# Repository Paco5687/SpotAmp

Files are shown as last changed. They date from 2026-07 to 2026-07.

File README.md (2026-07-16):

# SpotAmp 🎛️

**A standalone desktop Spotify player with real motorized faders, physical
buttons, and a WinAmp-inspired soul.** Raspberry Pi + RP2040, open hardware and
software (MIT). It sits on your desk on a pop-out stand, plays Spotify with **no
phone and no cloud remote** — and when you load an EQ preset, the faders
physically glide into place.



> *It really whips the llama's ass.* (Inspired by [Eslam Mohamed's WinAmp
> hardware concept](https://www.yankodesign.com/2024/04/27/modular-media-player-concept-brings-iconic-winamp-design-to-the-physical-world/) — but real, and it plays.)

## The screen (running today on the device)

The center of the unit is a square 720×720 touchscreen (HyperPixel 4.0) running
a compact multi-view UI — switched by dedicated physical buttons:

| Now Playing | Playlists | Up Next |
|---|---|---|
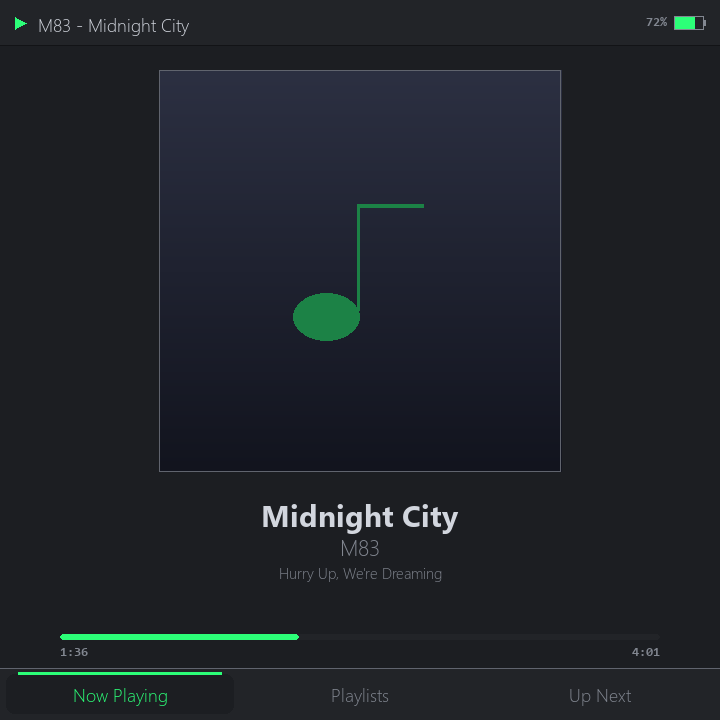
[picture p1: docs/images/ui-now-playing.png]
Now Playing
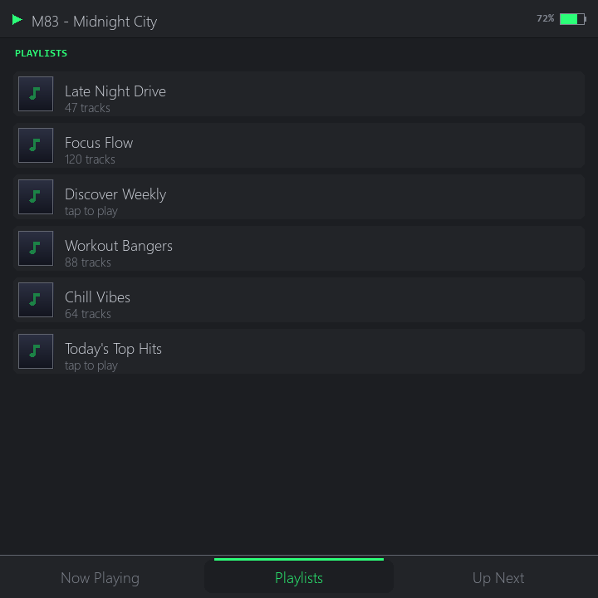
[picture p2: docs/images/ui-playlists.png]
Playlists
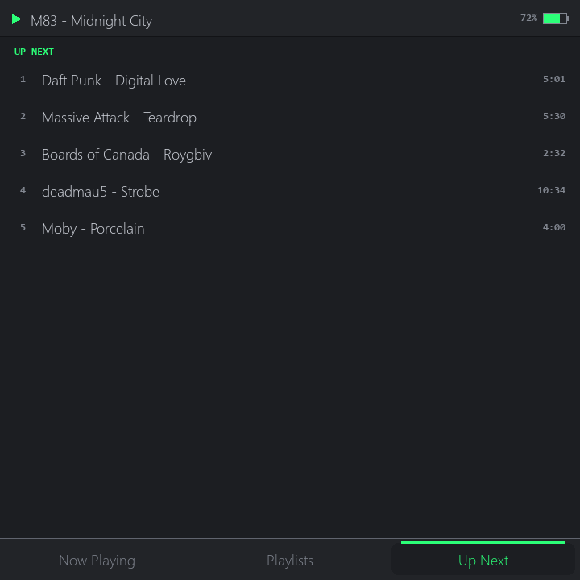
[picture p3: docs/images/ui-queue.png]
Up Next
|  |  |  |

This already runs **standalone on the Pi**: boots straight into the UI (kiosk),
streams via go-librespot, browses your real library, plays through its own
speakers-to-be. Transport, EQ, volume, and seek live in *hardware* — including a
**seek fader that physically tracks the song**.

## The hardware design

| System wiring | RP2040 pinout |
|---|---|
| System wiring | Pico pinout |

**Front panel** — dimensioned, parametric, CAD-ready
([DXF for SketchUp / SVG for Blender](hardware/cad/)):

Front panel cut drawing

Envelope **175 × 280 × 32 mm** (6.9″ × 11″), FDM prototype → CNC **anodized
aluminum** final, with aluminum knobs and a fold-out kickstand.

## How it works

```
        ┌───────────────────────────┐        USB serial        ┌──────────────────────┐
        │     Raspberry Pi 4 B       │◀───────(ASCII)──────────▶│  RP2040 (Pico)       │
        │                            │                          │                      │
        │  go-librespot ─▶ ALSA EQ ─▶│─▶ USB DAC ─▶ amp/spkrs   │  buttons · encoders  │
        │        │            ▲      │                          │  amber OLED readout  │
        │  Spotify Web API    │      │   FADER <id> <pos> ──────▶  10 motorized faders │
        │        │            │      │                          │   (PID position loop)│
        │  multi-view UI ─────┘      │◀──── EV BTN/FADER/BAT ───│  battery · touch     │
        └───────────────────────────┘                          └──────────────────────┘
             720×720 touchscreen                                 I2C: PCA9685×2 · MPR121
                                                                      MCP23017 · TPA2016
```

Two brains: the Pi runs Spotify + the screen; the RP2040 owns real-time I/O and
the fader PID loops. Full detail: [docs/architecture.md](docs/architecture.md) ·
[serial protocol](docs/serial-protocol.md) · [wiring + pin maps](hardware/wiring.md).

## Status

**Working now** — standalone playback on the device (no phone), kiosk boot,
touch UI (now playing / playlists / queue), real album art, Spotify Connect
control path, complete RP2040 firmware (compiled, awaiting parts), dimensioned
panel drawing, full parts list.

**Next** — order parts → single-fader PID bring-up → OLED + buttons → motorized
EQ → speakers/amp → battery → enclosure. Live plan on the
**[project board](https://github.com/users/Paco5687/projects/4)**.

## Build one

| | |
|---|---|
| 🛒 [Parts list](hardware/PARTS.md) | real SKUs, ~$450–515 + Pi/screen |
| 📄 [BOM + rationale](hardware/BOM.md) | why every part is there |
| 🔌 [Wiring & schematics](hardware/wiring.md) | address maps, pin budget, diagrams |
| 📐 [Panel CAD](hardware/cad/) | parametric DXF/SVG generator |
| 🧲 [Enclosure notes](hardware/enclosure.md) | machining rules, kickstand, findings |
| 🥧 [Pi bring-up](docs/pi-bringup.md) | reproducible standalone-player setup |
| 🎹 [Firmware](firmware/) | RP2040, PlatformIO, bench bring-up guide |

Try the UI on any machine (no hardware, no account):

```bash
cd pi && pip install -r requirements.txt && python -m spotamp
```

## The honest hard parts

- **Spotify Premium required** — playback uses [go-librespot](https://github.com/devgianlu/go-librespot)
  (unofficial). Browsing uses the Web API in Dev Mode (see
  [docs/spotify-setup.md](docs/spotify-setup.md) for the one-time standalone auth).
- **Motorized faders are the cost/complexity center** (~$200+ of the build) —
  and the reason this thing will be cool.
- The HyperPixel takes **all 40 GPIO**, so everything else rides USB + an I2C
  expander architecture — see [hardware/wiring.md](hardware/wiring.md).

## Naming & trademarks

SpotAmp is an independent, unofficial hobby project. It is **not affiliated with,
endorsed by, or sponsored by Spotify** (you bring your own Premium account and
developer app), and it is not associated with WinAmp/Llama Group — the UI is an
original homage to the classic WinAmp aesthetic, with no assets from it.

*(Formerly "WinAmpPlayer" — old links redirect.)*

## License

[MIT](LICENSE) — build one, remix it, tell us how it goes.

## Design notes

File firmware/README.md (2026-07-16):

# Firmware (RP2040 / Raspberry Pi Pico)

Owns all physical I/O and the real-time motor loops for the motorized faders.
Talks to the Pi over USB serial using the [serial protocol](../docs/serial-protocol.md).

## Build

Uses [PlatformIO](https://platformio.org/) with the Arduino core for RP2040
(`earlephilhower/arduino-pico`):

```bash
cd firmware
pio run                 # build
pio run -t upload       # flash (hold BOOTSEL on first flash, or use the reset)
pio device monitor      # watch the serial link
```

## What it does

- Reads buttons (via MCP23017), encoders, the balance pot, and all fader wiper
  positions (through a CD74HC4067 analog mux, since the Pico has only 3 ADC
  channels).
- Runs a per-fader **PID loop** at ~1 kHz driving each motorized fader toward the
  target the Pi last sent (`FADER <id> <pos>`), and yields the motor while the
  user is touching that fader (MPR121 touch electrodes).
- Drives the **amber OLED readout** (SSD1322 over SPI) from `DISP` commands the
  Pi streams (title / time / stream info).
- Emits `EV …` events upstream (button presses, user fader moves, touch, encoders).

> **I/O architecture:** motor PWM goes through **2× PCA9685** and buttons/touch
> through **MCP23017/MPR121**, all on one I2C bus — direct-wiring doesn't fit the
> Pico's 26 GPIO. Full pin budget in [../hardware/wiring.md](../hardware/wiring.md).
> The `main.cpp` skeleton still drives one fader on direct pins for bring-up;
> switch to the PCA9685 when scaling past one.

The firmware is **fully built out** (desk-written 2026-07-16, compiles clean,
untested on hardware): every I2C device driver, the OLED readout with the `DISP`
marquee, buttons/encoders/touch/battery events, and the per-fader PID against
the PCA9685. `src/config.h` holds all pins, addresses, and tuning constants —
including **feature flags** (`HAS_PCA9685`, `HAS_OLED`, …) so bench bring-up can
enable one subsystem at a time. A missing I2C board logs `... MISSING` and
degrades instead of hanging.

## Bring-up order (with the full firmware)

1. Flash with **all `HAS_*` flags off except none needed** — `PING`→`PONG` over
   USB proves the link (`LOG spotamp-fw ready`).
2. Enable `HAS_MCP23017` → press buttons, watch `EV BTN`. Encoders are always
   on (direct GPIO) — turn them, watch `EV ENC`.
3. Wire fader #1 (wiper → mux ch0, motor → PCA A ch0/1, touch → MPR121 e0);
   enable `HAS_PCA9685` + `HAS_MPR121`. Send `FADER 0 512` — tune `PID_KP/KD`
   and `PWM_MIN_MOVE` (stiction floor) in `config.h` until it glides.
4. Enable `HAS_OLED` — the Pi's `DISP` stream should show time + title.
5. Enable `HAS_TPA2016` + `HAS_MAX17040` — battery `EV BAT` every 5 s, jack
   insert mutes the amp.
6. Scale to all 10 faders.

⚠️ Safety built in: PCA9685 **/OE is held high (motors disabled) until the
firmware has zeroed all channels** — no fader slam on boot.

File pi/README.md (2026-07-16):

# Pi app — `spotamp`

The Python/Pygame application: the WinAmp-style UI, Spotify control, and the
bridge to the microcontroller. Runs **fully mocked on a laptop** so you can build
the UI with no hardware and no Spotify account.

## Run (mock mode — default)

```bash
cd pi
pip install -r requirements.txt   # pygame is all you need for mock mode
python -m spotamp
```

Requires **Python 3.11+** (uses the stdlib `tomllib`).

A square (720×720) **multi-view** window opens — the device screen: **Now Playing**,
**Playlists**, **Up Next**. On the real device these views are switched by dedicated
physical buttons; transport/EQ/faders are hardware, not on screen.

**Controls in the window (dev):**

| Input | Action |
|---|---|
| Tabs / `1` `2` `3` / `Tab` | switch view (Now Playing / Playlists / Up Next) |
| Tap a playlist row | open + play that playlist |
| `space` | play/pause |
| `←` / `→` | prev / next |
| `↑` / `↓` | volume |
| `s` | stop · `q` / `Esc` quit |

## Connect Spotify (Web API — playlists & album art)

No website or hosting needed — it uses a **loopback redirect + PKCE**.

1. Create an app at https://developer.spotify.com/dashboard.
2. Add this **exact** redirect URI (Spotify banned `localhost`; loopback HTTP is fine):
   ```
   http://127.0.0.1:8888/callback
   ```
3. Put the app's **Client ID** in `config.toml` as `spotify_client_id` (no secret needed).
4. Authorize once:
   ```bash
   python -m spotamp.authorize
   ```
   A browser opens, you approve, and a refresh token is cached to
   `pi/spotify_token.json` (gitignored). The device refreshes tokens forever after that.

`go-librespot` (the audio playback) authenticates **separately and standalone** —
using its own one-time **interactive OAuth** login (no phone required; a phone via
Spotify Connect is only an optional alternative). It needs Premium. See
[../docs/spotify-setup.md](../docs/spotify-setup.md) for both one-time logins.

## Run against real hardware

Copy `config.example.toml` → `config.toml` and set:

```toml
backend  = "librespot"      # needs a running go-librespot + Spotify Premium
controls = "serial"         # needs the RP2040 flashed and connected
serial_port = "/dev/ttyACM0"
fullscreen = true           # on the device LCD
```

`requests` and `pyserial` (in `requirements.txt`) are only needed for real
hardware; they're imported lazily so mock mode doesn't require them.

## Layout

```
spotamp/
├── __main__.py      # python -m spotamp (also: `authorize` subcommand)
├── app.py           # main loop, action routing, MOTOR SYNC, queue/battery polls
├── config.py        # config.toml loader (zero-config defaults)
├── models.py        # PlayerState / Track — the source of truth
├── spotify.py       # MockPlayer / WebApiPlayer / LibrespotPlayer (PlayerBackend)
├── spotify_web.py   # Web API client: playlists, queue, playback control
├── spotify_auth.py  # loopback PKCE OAuth + token cache
├── library.py       # async playlist browsing (BrowseState)
├── images.py        # async album-art download + cache
├── power.py         # battery sources (mock / Geekworm X728)
├── controls.py      # serial protocol + MockControls / SerialControls
└── ui/
    ├── skin.py      # palette + Rect drawing helper
    └── screen.py    # the multi-view screen UI (Now Playing / Playlists / Up Next)
```

Tests live in [`tests/`](tests/) — run `python -m pytest tests` from `pi/`.
See [../docs/architecture.md](../docs/architecture.md) for how it all fits.

## Playback backends

Set `backend` in `config.toml`:

| `backend` | What plays the audio | Use it for |
|---|---|---|
| `mock` (default) | nothing — simulated playback of a demo/owned playlist | UI dev on a laptop |
| `librespot` | **go-librespot on this machine** (the device path) | the real device |
| `webapi` | any active Spotify Connect device via the Web API | laptop dev with real audio |

Tapping a playlist plays it **by context URI**, which works for owned *and*
followed/editorial playlists (Dev Mode only restricts *reading* their track
lists, not playing them). The **Up Next** view shows the live playback queue
(`GET /me/player/queue`), so you still get a tracklist for anything playing.

## Notes / TODO

- **Album art** is real (fetched + cached async in `images.py`); a drawn
  placeholder shows until each image lands.
- **Spectrum analyzer** returns in Phase 4 with the real FFT audio tap.
- **EQ** currently just stores band gains; the ALSA software-EQ pipeline that
  applies them is Phase 4 (see the project board).

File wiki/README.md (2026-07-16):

# Wiki source

These Markdown files are the **source for the GitHub Wiki**. GitHub stores a
wiki in a separate git repo (`SpotAmp.wiki.git`), so to publish:

1. Create the wiki by adding one page in the repo's **Wiki** tab (this
   initializes `….wiki.git`).
2. `git clone git@github.com:Paco5687/SpotAmp.wiki.git`
3. Copy these files in, `git add -A && git commit && git push`.

Page names map to titles (`Bill-of-Materials.md` → "Bill of Materials").
`Home.md` is the landing page; `_Sidebar.md` is the nav. **Placeholders for now** —
most pages link to the authoritative docs under [`/docs`](../docs) and
[`/hardware`](../hardware) so there's a single source of truth.

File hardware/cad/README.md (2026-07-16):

# CAD — front panel

**`front-panel.dxf`** (SketchUp Pro / any CAD) and **`front-panel.svg`**
(Blender-native curve import) are both generated from
[`generate_panel.py`](generate_panel.py) — one parametric source of truth where
every dimension is a named constant traced to a datasheet. **Don't hand-edit the
DXF/SVG; edit the parameters and regenerate** (`python generate_panel.py`).

Current envelope: **175 × 280 × 32 mm** (see the height/width findings in
[../enclosure.md](../enclosure.md) — the fader mounting span drives everything).

## Layers

| Layer | Meaning | Action in CAD |
|---|---|---|
| `OUTLINE` | panel perimeter (R4 corners) | cut |
| `CUTOUTS` | windows + fader/pot slots + button holes | cut through |
| `HOLES` | mounting screw holes (true diameters: M3 clearance 3.4, pot mounts 2.4) | drill |
| `GRILLE` | speaker grille pattern (ø2, hex pitch 4.5) | drill |
| `ENGRAVE` | labels | engrave/laser — **do not cut** |
| `REF` | component bodies **behind** the panel (faders, OLED, HyperPixel) | placement aid — **delete before cutting** |
| `DIM` | notes | delete after import |

## Import

**SketchUp Pro**: File → Import → DXF, units **millimeters**. Each layer arrives
as a tag. To make the 3D panel: select the outline + cut layers → Push/Pull to
panel thickness (2–3 mm), using `REF` to position the component models. The ALPS
fader **STEP model** is downloadable from the ALPS product page (link in
[../datasheets/README.md](../datasheets/README.md)).

**Blender**: File → Import → SVG (native). Curves arrive true-to-mm (1 unit =
1 mm at default SVG import scale — verify with the 175 mm outline). Extrude the
curves for the panel solid.

## Before cutting anything

- Cross-check every **VERIFY**-marked constant in `generate_panel.py` against the
  physical part (fader M3 span & slot, HyperPixel bezel, OLED window, slide-pot
  mounts) — datasheet revisions and clone parts vary.
- The checker enforces 2D clearances only. Two known **3D stacking questions**
  for CAD: (1) transport-button PCB vs the volume fader body (~0.75 mm apart
  behind the panel), (2) grille back-volume vs the seek fader motor. Both have
  room to shift a few mm if needed — change the constant, regenerate.
- Grille zones are modest (24×16 mm each); the side walls can carry additional
  grille if the speakers want more open area — that's a body decision, not a
  panel one.

## Sanity checks built into the generator

Bounds (everything inside the walls) + all-pairs clearance between every cut
feature (circle/rect/rect-circle, ≥1.5 mm). The generator **refuses to emit** a
drawing that fails — extend the checks rather than bypassing them.

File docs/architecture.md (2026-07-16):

# Architecture

## Why two brains

The Pi runs Linux, which is non-deterministic under scheduling load — fine for
UI and networking, bad for a tight motor-control loop that has to run at a
steady ~1 kHz to keep motorized faders from oscillating. So:

- **Raspberry Pi** — Spotify client, audio pipeline, the LCD UI, high-level
  logic. Sends *targets* ("move volume fader to 72%").
- **RP2040 microcontroller** — soft-real-time I/O. Owns the PID loops that drive
  each motorized fader to its target, debounces buttons, reads pots/encoders,
  and streams events up to the Pi.

They talk over a simple newline-delimited ASCII protocol on USB serial. See
[serial-protocol.md](serial-protocol.md).

## Alternative platforms (future / v2)

The **[Arduino Uno Q](https://docs.arduino.cc/hardware/uno-q/)** is architecturally
this exact design on a single board: a Qualcomm Dragonwing QRB2210 (quad
Cortex-A53, runs Debian Linux) **plus** an STM32U585 (Cortex-M33) real-time MCU,
with an internal bridge — i.e. our "Pi brain + RP2040 brain" fused, plus eMMC.

We're **staying on Pi 4 B + RP2040 for v1** because: the Uno Q's MIPI-DSI display
and analog audio come out only via a separate carrier board; it's brand-new
(Oct 2025) with an unproven ecosystem/supply — risky for a build others must
reproduce; and we already have a working Pi stack. It's a strong **v2 candidate**
if its ecosystem matures — it could collapse both boards into one.

## Audio path

```
Spotify ──▶ go-librespot ──▶ ALSA (software graphic EQ) ──▶ USB DAC ──▶ switched 3.5mm jack
                                    ▲                  │                     │ (no plug)
                          EQ gains from faders         │              TPA2016 amp ──▶ internal
                                                       │             (I2C, RP2040 bus)  speakers
                                          audio tap ──▶ FFT ──▶ spectrum bars (UI)
```

> The DAC is **USB** (not a GPIO I2S HAT) because the HyperPixel display's DPI
> interface consumes all 40 GPIO pins, including I2S. The Pi's 3.5 mm jack works
> for bring-up. **Standalone playback** comes from internal enclosed speakers via
> a TPA2016 Class-D amp; inserting headphones mutes the amp (jack detect →
> firmware). External outputs are software: **Spotify Connect transfer** (Sonos &
> co. via the Web API — no audio plumbing) and **Bluetooth A2DP** from the Pi 4's
> onboard radio.

- **go-librespot** is a full Spotify client that streams and decodes audio
  directly (requires Premium). It authenticates **standalone via interactive
  OAuth** — a one-time browser login, then it reconnects on cached credentials
  forever, no phone. It exposes an HTTP + WebSocket API for transport and
  now-playing metadata. (Zeroconf/"pick it from a phone" is an optional mode we
  don't rely on.)
- The **graphic EQ is ours** — Spotify exposes no EQ over the API, so we insert a
  software EQ into the ALSA chain (e.g. an `ladspa`/`caps` multi-band plugin, or
  a custom filter). The motorized EQ faders set its band gains.
- A **loopback/monitor tap** feeds a small FFT so the spectrum analyzer reflects
  the actual audio, not a simulation. (In mock mode it's simulated.)

## The Pi app (`pi/spotamp/`)

| Module | Responsibility |
|---|---|
| `models.py` | `PlayerState`, `Track` — the single source of truth the UI renders |
| `spotify.py` | `MockPlayer` (simulation), `WebApiPlayer` (drive any Connect device), `LibrespotPlayer` (the on-device player) behind one `PlayerBackend` interface |
| `spotify_web.py` / `spotify_auth.py` | Web API client (playlists, queue, control) + loopback-PKCE auth |
| `library.py` / `images.py` / `power.py` | Async playlist browsing, album-art cache, battery sources |
| `controls.py` | Serial protocol + `MockControls` / `SerialControls` |
| `ui/skin.py` | Palette + shared drawing helpers |
| `ui/screen.py` | Compact **multi-view** screen UI (Now Playing / Playlists / Queue) for the square LCD; turns touch/buttons into actions |
| `app.py` | Main loop, action routing, and **motor sync** |

### Motor sync — the signature trick

Every frame, `app._sync_motors()` computes where each motorized fader *should*
be from `PlayerState` (volume, seek progress, EQ band gains) and sends a
`FADER <id> <pos>` target — **unless the user is currently touching that fader**
(tracked via `EV TOUCH` events). So:

- Change the song → the **seek fader glides** to the new position and tracks it.
- Load an EQ preset → the **EQ faders physically animate** into the curve.
- Grab a fader → the motor yields; when you let go, it holds your value.

### Backend abstraction

`PlayerBackend` is a `Protocol`. `MockPlayer` advances a demo playlist with no
network so the entire UI is buildable on a laptop. `LibrespotPlayer` maps the
same methods onto go-librespot's local HTTP API (the on-device path);
`WebApiPlayer` drives any active Spotify Connect device through the Web API
(useful for laptop dev with real audio). Swap via `config.toml`.

## Central screen & UI direction

The device is **physical-first**: transport, EQ, and faders are hardware; the
screen is a small **square** LCD (**HyperPixel 4.0 Square, 720×720**) showing the
compact **multi-view** UI in `ui/screen.py` — one view at a time, switched by
**dedicated physical buttons** (ButtonId 9–11 in the serial protocol; on-screen
tabs and keys `1`/`2`/`3` in dev). v1 views: Now Playing, Playlist selector, Play
Queue (Search later). Playback control uses `backend = "librespot"`
(go-librespot's local API on :3678), so control stays on the Pi — no cloud
round-trip. The HyperPixel's DPI takes all GPIO, so audio → USB DAC and battery
sensing → RP2040 (see hardware/BOM.md).

## Deployment on the Pi

The full, tested procedure is **[pi-bringup.md](pi-bringup.md)**. In short:

1. `go-librespot` as a systemd service, authenticated once via interactive
   OAuth (standalone; see [spotify-setup.md](spotify-setup.md)).
2. HyperPixel 4.0 Square via the `vc4-kms-dpi-hyperpixel4sq` overlay; rotation
   done at the **compositor** level so touch follows the display.
3. The UI as a systemd **user** service (kiosk): boots straight into the app,
   fullscreen, cursor hidden (`deploy/spotamp-kiosk.*`).
4. *(Phase 4)* ALSA EQ between librespot and the USB DAC.
5. *(Phase 5)* RP2040 flashed and enumerated at `/dev/ttyACM0`.

## Roadmap

Tracked live on the **[project board](https://github.com/users/Paco5687/projects/4)**
(milestones Phase 1–9 plus "UI Redesign & Central Screen"). Done so far: desktop
mock, Spotify integration (auth/browse/playback/queue), standalone audio on the
Pi, HyperPixel + kiosk autostart, the multi-view screen UI. Next up:
playlist-detail view + list scrolling, RP2040 physical controls, motorized
faders, software EQ + real spectrum, power/battery, enclosure.

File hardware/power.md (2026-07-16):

# Power & Battery Design

The unit is handheld, so it runs from an internal battery with a regulated 5 V
rail, safe charging, battery monitoring, and a clean shutdown that protects the
SD card. This document sizes the system, recommends a topology that's easy for
others to replicate, and lists the tradeoffs.

> Status: **design + placeholders.** Cell counts, runtimes, and part choices are
> engineering estimates — verify against the specific boards/cells you buy.

## 1. Power budget

Measured/typical draw on a **Raspberry Pi 4 B** based system. Motors are the
spiky load — they only draw current *while moving*, and our firmware cuts motor
power once a fader reaches its target, so the holding current is ~0.

| Subsystem | Typical | Peak | Notes |
|---|---:|---:|---|
| Pi 4 B (app + Wi-Fi + audio) | 4.5 W | 7 W | 4 cores + USB busy |
| 4″ DSI/HDMI LCD + backlight | 1.2 W | 2 W | backlight dominates |
| I2S DAC + headphones | 0.3 W | 0.5 W | |
| speaker amp (TPA2016, internal stereo) | 1 W | 3 W | standalone playback; ~0 W with headphones (amp muted) |
| RP2040 + mux + LEDs | 0.4 W | 1 W | |
| Motorized faders (10×) | ~0.2 W avg | **~12–15 W** | brief spikes when several move at once |
| **System** | **~6.5 W avg** | **~20 W peak** | design the 5 V rail for **5 A** headroom |

Key takeaways:
- **Average ≈ 6.5 W.** That's what sets runtime.
- **Peaks to ~20 W** for <1 s when a preset loads and many faders slew together.
  The 5 V regulator must survive that; handle it with **bulk capacitance
  (1000–2200 µF) at the motor-driver rail** so spikes come from the caps, not the
  battery/regulator.

## 2. Recommended topology

For a project other people will replicate, favor a **safe, off-the-shelf,
monitored** solution over a hand-rolled pack:

```
 18650 Li-ion cells ─▶ UPS/BMS HAT ─▶ regulated 5 V (up to 5 A) ─▶ Pi 4 B + everything
        ▲                   │  │
   USB-C / DC charge ───────┘  └── I2C: battery %, voltage, AC-loss  ─▶ Pi (safe shutdown + UI meter)
```

**Baseline:** a Pi-oriented UPS HAT that takes 18650 cells, outputs a solid
5 V/5 A, and reports battery state over I2C — e.g. **Geekworm X728** (2×18650,
auto power-on, AC-loss detect, documented safe-shutdown scripts) or **Waveshare
UPS HAT (B)** (2×18650, 5 V/5 A, INA219 fuel gauge). Verify current model numbers
and Pi 4 compatibility before buying — SKUs churn.

Why a HAT and not a bare pack: you get **cell protection, a proven 5 V boost
rated for Pi 4 peaks, charge management, and I2C monitoring** in one board — the
hard, safety-critical parts done right.

**Decision (v1): Geekworm X728.** Its MAX17040 fuel gauge (I2C `0x36`) is what
`pi/spotamp/power.py` (`X728Battery`) reads for the on-screen meter and
safe shutdown; it has documented shutdown scripts and AC-loss detection. Waveshare
UPS HAT (B) remains a drop-in alternative — swap the reader class if you use it.
For more runtime, feed a larger 18650 pack (4–6 cells) to the board's terminals.

## 3. Sizing the battery ("large" is the goal)

18650 cell ≈ 3500 mAh @ 3.6 V ≈ **12.6 Wh** raw. After boost efficiency (~90 %)
and a safe depth-of-discharge (~85 %), figure **~9.6 Wh usable per cell**. At the
~6.5 W average:

| Pack | Raw Wh | Usable Wh | Runtime @6.5 W | Notes |
|---|---:|---:|---:|---|
| 2 × 18650 | 25 | ~19 | **~3 h** | fits a 2-cell HAT; thin |
| 4 × 18650 | 50 | ~38 | **~6 h** | sweet spot for "large" |
| 6 × 18650 | 76 | ~58 | **~9 h** | needs a bigger body/pack |
| 8 × 18650 | 101 | ~77 | **~12 h** | ⚠ **>100 Wh = no airline carry-on** |

For "large batteries," target **4–6 cells**. Options to get there:
- a **4-cell UPS board**, or
- an **external 2S2P / 2S3P 18650 pack** wired to the HAT's cell terminals, or
- higher-capacity cells (Molicel P28A, Samsung 35E, LG MJ1).

**Airline note:** keep total under **100 Wh** if the device should be flyable;
loose spare cells have their own carry-on rules.

## 4. Cells: 18650 vs LiPo pouch (a real form-factor tradeoff)

| | 18650 Li-ion | LiPo pouch |
|---|---|---|
| Shape | cylindrical Ø18 × 65 mm | flat, custom W×H, thin |
| Fit in a 1″ (25 mm) body | tight next to 60 mm faders | **better** — lies flat |
| Safety / replaceability | **excellent**, standardized, swappable | fussier, needs careful protection |
| Best for | a shareable, safe DIY build | a genuinely thin body |

**Recommendation:** default to **18650** for safety and replaceability (this is a
public build others will copy). If you insist on the slim 1″ book profile, a
**flat LiPo pouch + a good 2S BMS + 5 V buck** is mechanically nicer — but note
that **a large battery may push the body past 1″**; faders already want ~20 mm of
depth, and an 18-mm cell beside them is tight. Call this out in the enclosure CAD.

## 5. Charging

- Charge over the HAT's **USB-C (or DC) input**; the UPS provides pass-through so
  the unit can run while charging.
- Charge current is typically **1–2 A** — a big 4–6 cell pack will take **several
  hours** to fill. If that's annoying, pick a board/charger that supports higher
  charge current and use a capable USB-PD supply.
- **Never** charge unbalanced multi-cell packs without a balancing BMS.

## 6. Safe shutdown + battery UI (software milestone)

The UPS HAT exposes battery voltage / state-of-charge over **I2C**. The Pi should:
1. Read SoC periodically (INA219 / fuel gauge / board's ADC).
2. Show a **WinAmp-style battery meter** on the LCD (a natural fit for the skin).
3. On **low battery** (~5 %) or **AC-loss + threshold**, trigger a clean
   `shutdown` so the SD card isn't corrupted.

Planned code: `pi/spotamp/power.py` (battery monitor) + a battery widget in
the UI. *Placeholder for now* — implement once the specific UPS board is chosen,
since the I2C register map is board-specific.

## 7. Grounding & wiring notes

- Join **motor ground** and **logic ground** at a single star point near the
  regulator; H-bridges inject noise.
- Put the **bulk caps physically at the DRV8833 rails**, not near the Pi.
- Fuse the battery output; add a physical **power switch** on the 5 V rail (or use
  the HAT's soft-power button + auto-boot).
- Keep motor-current wiring short and thick; keep it away from the audio/DAC lines
  to avoid whine.

## 8. Open questions / TODO

- [ ] Pick the exact UPS board (2- vs 4-cell) and confirm 5 V/5 A + I2C monitoring.
- [ ] Decide 18650 vs LiPo once the enclosure thickness is locked.
- [ ] Bench-measure real average draw (esp. motor duty cycle) to firm up runtime.
- [ ] Implement `power.py` + battery meter + safe-shutdown against the chosen board.
- [ ] Verify total Wh vs the airline limit if portability matters.

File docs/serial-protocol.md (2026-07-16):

# Serial protocol (Pi ⇄ RP2040)

A deliberately simple, human-readable, newline-delimited ASCII protocol over USB
serial (CDC-ACM). ASCII because you can debug the whole thing with a serial
monitor. **115200 baud, 8N1.** Every message ends with `\n`.

The Python side is `pi/spotamp/controls.py`; the firmware side is
`firmware/src/main.cpp`. Keep both in sync with this document.

## Pi → microcontroller (commands)

| Command | Meaning |
|---|---|
| `FADER <id> <pos>` | Drive motorized fader `id` to position `pos` (0–1023). Engages the PID loop toward that target. |
| `FADER_RELEASE <id>` | Cut motor power on fader `id` so the user can move it freely. |
| `LED <index> <r> <g> <b>` | Set indicator LED color (0–255 each). |
| `DISP TITLE <text>` | Scrolling title line on the amber OLED readout (single line; sent on track change). |
| `DISP TIME <pos_ms> <dur_ms>` | Elapsed/total time for the OLED (sent ~1/s). |
| `DISP INFO <kbps> <khz>` | Stream info readout (bitrate / sample rate). |
| `PING` | Liveness check; expects `PONG`. |

## Microcontroller → Pi (events)

All events are `EV <TYPE> <id> <value>`:

| Type | `value` | Meaning |
|---|---|---|
| `EV BTN <id> <0\|1>` | 1 = pressed, 0 = released | Button state change (debounced). |
| `EV FADER <id> <0..1023>` | ADC position | A fader was moved **by the user** (only sent while touched/released, not while the motor is driving it). |
| `EV TOUCH <id> <0\|1>` | 1 = grabbed | User is touching a motorized fader. The Pi stops driving it until `0`. |
| `EV ENC <id> <±delta>` | signed detent count | Rotary encoder moved. |
| `EV POT <id> <0..1023>` | ADC value | Potentiometer moved (0 = balance). |
| `EV BAT 0 <0..1000>` | state-of-charge ×10 | Battery SoC from the X728's MAX17040 (on the RP2040 I2C bus), every ~5 s. |
| `EV CHG 0 <0\|1>` | 1 = on AC/charging | X728 power-loss-detect line. |
| `EV JACK 0 <0\|1>` | 1 = headphones in | Jack insertion. Firmware mutes the speaker amp itself; informational for the UI. |

Plus out-of-band: `PONG` (reply to `PING`) and `LOG <text>` (firmware debug,
ignored by the parser).

## IDs

**Faders** (`FaderId` in `controls.py`):

| id | fader | motorized |
|---|---|---|
| 0–6 | EQ bands (60, 150, 400, 1k, 2.4k, 6k, 15k Hz) | ✅ |
| 7 | Preamp | ✅ |
| 8 | Volume | ✅ |
| 9 | Seek (tracks song position) | ✅ |

**Buttons** (`ButtonId`): 0 prev · 1 play · 2 pause · 3 stop · 4 next ·
5 eject (spare) · 6 shuffle · 7 repeat · 8 eq-on/off · **9 view:now-playing ·
10 view:playlists · 11 view:queue** (the dedicated view-switch buttons for the
central screen) · 12 eq-preset (cycles presets; the motorized faders animate
into each curve) · **13/14 encoder push switches**.

**Pots** (`PotId`, via `EV POT`): 0 balance (L/R, non-motorized).

## Example exchange

```
→ PING
← PONG
← EV TOUCH 8 1            # user grabbed the volume fader
← EV FADER 8 742          # ...and moved it
← EV TOUCH 8 0            # let go
→ FADER 9 512            # Pi: glide the seek fader to 50% (new track)
← EV BTN 4 1             # user pressed NEXT
→ FADER 9 0             # Pi: seek fader back to start
```

## Design notes

- **Idempotent targets.** The Pi resends a fader target only when it changes
  (see `App._last_sent`), so the link stays quiet at idle.
- **User wins.** While a fader reports `TOUCH 1`, the Pi never fights it. This is
  what makes the motorized feel right.
- **Framing.** One message per line. The firmware ignores unknown verbs; the Pi
  ignores unparseable lines. Forward-compatible by construction.
- **Future:** if ASCII bandwidth ever bottlenecks (it won't at these rates),
  switch to a COBS-framed binary packet with the same semantics.

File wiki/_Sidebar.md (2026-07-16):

### SpotAmp

- [Home](Home)
- [Bill of Materials](Bill-of-Materials)
- [Assembly](Assembly)
- [Power and Battery](Power-and-Battery)
- [Software Setup](Software-Setup)
- [Spotify Setup](Spotify-Setup)
- [Firmware](Firmware)
- [Troubleshooting](Troubleshooting)

[Repo ↗](https://github.com/Paco5687/SpotAmp)

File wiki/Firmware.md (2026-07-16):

# Firmware (RP2040)

> **Placeholder** — see [firmware/README.md](https://github.com/Paco5687/SpotAmp/blob/main/firmware/README.md)
> and the [serial protocol](https://github.com/Paco5687/SpotAmp/blob/main/docs/serial-protocol.md).

The RP2040 (Raspberry Pi Pico) owns real-time I/O and the motorized-fader PID
loops, and talks to the Pi over a simple ASCII serial protocol.

- Build with PlatformIO (`arduino-pico` core): `cd firmware && pio run -t upload`.
- Bring-up order and pin map: see the firmware README.

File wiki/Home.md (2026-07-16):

# SpotAmp

A handheld, book-sized Spotify player styled after classic WinAmp — color LCD
touchscreen for the playlist, real physical buttons, pots, and **motorized
faders** for a graphic EQ plus volume and a seek fader that follows the song.

**Open source (MIT).** Build one yourself — this wiki has everything you need.

> ⚠️ **Placeholder wiki.** Content is being filled in as the build progresses.

## Start here
- **[Bill of Materials](Bill-of-Materials)** — every part + rough cost (~$430–480)
- **[Assembly](Assembly)** — wiring, enclosure, putting it together
- **[Power and Battery](Power-and-Battery)** — battery sizing, safe shutdown
- **[Software Setup](Software-Setup)** — flash, install, run
- **[Spotify Setup](Spotify-Setup)** — standalone auth (no phone needed)
- **[Firmware](Firmware)** — the RP2040 controls board
- **[Troubleshooting](Troubleshooting)**

## What it does
- Plays **Spotify** playlists (Premium) fully standalone — network + account only.
- WinAmp-style UI: green LCD readout, spectrum analyzer, album art, playlist.
- Motorized faders that physically track playback and EQ presets.

## Status
The core device works: a Pi 4 B that **boots straight into its own multi-view UI**
on a HyperPixel 4.0 Square touchscreen and plays Spotify **standalone** (no phone).
In progress: physical controls (RP2040), motorized faders, EQ + spectrum, battery,
enclosure. See the [project board](https://github.com/users/Paco5687/projects/4)
and [repo README](https://github.com/Paco5687/SpotAmp).

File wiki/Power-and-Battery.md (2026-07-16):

# Power and Battery

> **Placeholder** — full design + tradeoffs in the repo:
> **[hardware/power.md](https://github.com/Paco5687/SpotAmp/blob/main/hardware/power.md)**

TL;DR:
- ~**6.5 W average**, ~**20 W peak** (motor slews) → design the 5 V rail for **5 A**.
- Use a **Pi UPS/BMS HAT** (Geekworm X728 / Waveshare UPS HAT B) + **18650 cells**.
- **Runtime:** 2 cells ≈ 3 h · 4 cells ≈ 6 h · 6 cells ≈ 9 h.
- Keep total **under 100 Wh** if it needs to fly.
- Bulk caps at the motor-driver rail; I2C battery monitoring drives a safe
  shutdown + an on-screen battery meter.

See the repo doc for the 18650-vs-LiPo form-factor tradeoff and charging notes.

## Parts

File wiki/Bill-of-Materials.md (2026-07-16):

# Bill of Materials

> **Placeholder** — the authoritative, always-current BOM lives in the repo:
> **[hardware/BOM.md](https://github.com/Paco5687/SpotAmp/blob/main/hardware/BOM.md)**

Quick summary (full motorized build ≈ **$430–480**):

| Group | ~$ |
|---|---|
| Compute & display (Pi 4 B, LCD, DAC) | 117 |
| Motorized faders + drivers + mux | 193 |
| Buttons / knobs / LEDs | 13 |
| Power (UPS + 4×18650 — see [Power and Battery](Power-and-Battery)) | 75 |
| Body & misc | 35 |

A **reduced build** (only volume + seek motorized, plain EQ pots) is ~$300–330.

See the repo BOM for exact parts, sourcing notes, and the "why 7-band EQ" sizing.

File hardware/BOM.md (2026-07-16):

# Bill of Materials

Prices are rough USD, mid-2020s, single-unit hobby quantities. This is a
**buildable** BOM for the full build you chose: motorized graphic EQ + motorized
volume + motorized seek, single integrated body.

> 🛒 **Ready to order?** [PARTS.md](PARTS.md) is the vendor shopping list (real
> SKUs, Adafruit-first). Datasheets: [datasheets/](datasheets/). Case rules +
> dimension findings: [enclosure.md](enclosure.md).

> ⚠️ **Read the fader note first — it's the biggest cost and space driver.**

## Compute & display

| Part | Notes | ~$ |
|---|---|---|
| **Raspberry Pi 4 Model B (2–4 GB)** | The build target. Ample for Pygame + ALSA EQ + FFT, has a 3.5 mm jack, and is easier on the battery than a Pi 5. | 45 |
| microSD 32 GB (A1) | OS + app | 8 |
| RP2040 (Raspberry Pi Pico) | Real-time controls + motor PID + the OLED readout. Cheap, 26 GPIO, PIO, 3 ADC. | 4 |
| **Pimoroni HyperPixel 4.0 Square** (720×720, DPI, touch) | The center screen — a small square LCD showing a multi-view UI (now playing / playlists / queue). ⚠️ DPI uses **all 40 GPIO** — see notes below. | 55 |
| **Amber OLED readout strip** (SSD1322, 256×64, SPI) | The retro top readout: elapsed time, scrolling title, mini-spectrum. Driven by the **RP2040** (`DISP` serial commands), not the Pi. | 25 |
| **USB DAC** (e.g. Sabrent/generic) | Audio out. A GPIO I2S HAT can't be used (HyperPixel's DPI takes the I2S pins). Pi 3.5 mm jack works for early testing. | 15 |
| **TPA2016 stereo 2.8 W Class-D amp** | Internal speakers. I2C gain/AGC/mute — rides the **RP2040 expander bus** (5th device). | 10 |
| **Enclosed stereo speakers, 3 W 4 Ω** (70×30×17 mm ea.) | Sealed backs = no custom acoustic chamber. Standalone playback, no headphones needed. | 8 |
| **Switched 3.5 mm headphone jack** | Insert detection (→ MCP23017 spare input) mutes the amp — headphones optional. | 2 |

> **HyperPixel I/O note:** the HyperPixel's DPI interface consumes all 40 GPIO
> pins (incl. standard I2C and I2S). That's fine here because everything else is on
> **USB**: controls/pots/faders **and battery sensing** run on the **RP2040** (USB
> serial), **audio** goes to a **USB DAC**, and the **UPS powers the Pi via USB-C**
> rather than stacking on the header. An alternate I2C is broken out on BCM 10/11 if
> ever needed. This is exactly why the two-brain (Pi + RP2040) split pays off.

## The motorized faders (the expensive part)

Full build = **10 motorized faders**: 7 EQ + 1 preamp + 1 volume + 1 seek.

| Part | Qty | Notes | ~$ ea | ~$ |
|---|---|---|---|---|
| ALPS RSA0N11M9 **60 mm motorized** fader | 10 | 100 mm won't fit a 5″ body — use 60 mm. Each has a motor + a wiper pot for position feedback + a touch-sense pin. | 18 | 180 |
| DRV8833 dual H-bridge motor driver | 5 | One drives two fader motors. | 2 | 10 |
| CD74HC4067 16-ch analog mux | 1–2 | The Pico has only 3 ADC channels; mux the 10 fader wipers + balance pot through one ADC. | 1.5 | 3 |
| **PCA9685 16-ch PWM driver** | 2 | ⚠️ **Required** — 10 motors need 20 PWM lines; the Pico doesn't have them. Drives the DRV8833 inputs over I2C. Caveat: ~1.5 kHz max PWM = brief audible buzz *while a fader moves* (moves are short; the reduced build avoids this entirely). | 5 | 10 |
| **MPR121 12-ch capacitive touch** | 1 | All 10 fader touch-sense lines over I2C (the ALPS conductive-knob pin is exactly what this reads). | 8 | 8 |
| **MCP23017 16-ch GPIO expander** | 1 | All 13 panel buttons over the same I2C bus — keeps the Pico's pin budget closing. | 2 | 2 |

> **Why the expanders:** direct-wiring everything needs ~55 signals; the Pico has
> 26 GPIO. With PCA9685 (motor PWM) + MPR121 (touch) + MCP23017 (buttons) sharing
> one 2-pin I2C bus, the budget closes with room for the OLED. Full pin map in
> [wiring.md](wiring.md).

**Why 7-band EQ, not 10:** eleven fader bodies (18.5 mm wide each, per the ALPS
datasheet) would need ~220 mm of width. Seven EQ + preamp (8 in the bank) need
~155 mm — which sets the body width at **~165 mm** (the original 127 mm/5″ target
can't hold a motorized bank; options in [enclosure.md](enclosure.md)). Volume +
seek mount horizontally. See [wiring.md](wiring.md).

**Want to cut cost/scope?** Make only **volume + seek** motorized (2 faders) and
use plain (non-motorized) slide pots for EQ. Saves ~$140 and most of the motor
drivers/PID work. The firmware already separates "motorized" from "read-only"
faders, so this is a config change, not a rewrite.

## Buttons, knobs, encoders

| Part | Qty | Notes | ~$ |
|---|---|---|---|
| Momentary tactile buttons (12 mm) | 13 | 5 transport + shuffle + repeat + eq-on + **eq-preset** + **3 view-switch** + eject/spare (ButtonId 0–12, read via the MCP23017) | 7 |
| Rotary encoder w/ push (EC11) | 2 | playlist scroll + select; menu | 4 |
| **Balance slide pot (non-motorized, 45 mm)** | 1 | The L/R slider from the concept — read via the mux as `POT 0`. | 2 |
| Addressable LED (WS2812) strip/segment | 1 | VU / status glow | 3 |

## Power (handheld) — see [power.md](power.md) for the full design

| Part | Notes | ~$ |
|---|---|---|
| UPS/BMS HAT for Pi (Geekworm X728 or Waveshare UPS HAT B) | 5 V/5 A out, 18650 holders, I2C battery monitoring + safe shutdown. | 30 |
| 18650 Li-ion cells ×4 (3500 mAh, e.g. Samsung 35E) | ~50 Wh ≈ 6 h runtime. Use 2 for ~3 h, 6 for ~9 h. | 40 |
| Bulk caps (1000–2200 µF) + fuse + power switch | Absorb motor-slew spikes at the driver rail. | 5 |

## Body & misc

| Part | Notes | ~$ |
|---|---|---|
| Enclosure (book form, ~175×280×32 mm, proven in cad/ — see [enclosure.md](enclosure.md)) | FDM prototype (PETG/ABS), CNC anodized aluminum final. | 15+ |
| Fader knob caps, standoffs, JST wiring, protoboard/PCB | | 20 |

## Rough total

| Group | ~$ |
|---|---|
| Compute & display & audio (incl. OLED, amp, speakers) | 172 |
| Motorized faders + drivers + mux + I2C expanders | 213 |
| Buttons/knobs/LEDs | 16 |
| Power (UPS + 4×18650, see [power.md](power.md)) | 75 |
| Body & misc | 35 |
| **Total (full motorized build)** | **≈ 510–560** |
| *Reduced (only volume+seek motorized, plain EQ pots)* | *≈ 360–390* |

## Sourcing notes

- Motorized faders: Mouser/Digikey for genuine ALPS; budget clones exist on
  AliExpress but wiper quality/backlash varies — buy one and test before ten.
- Confirm the fader's touch-sense wiring; some variants need a capacitive
  touch IC, others expose a conductive-knob pin.
- HyperPixel: verify the `vc4-kms-dpi-hyperpixel4sq` overlay + touch on your OS
  version before committing to the enclosure cutout (see docs/pi-bringup.md).
- SSD1322 OLED strips ship in SPI/parallel variants — order the **SPI** one.

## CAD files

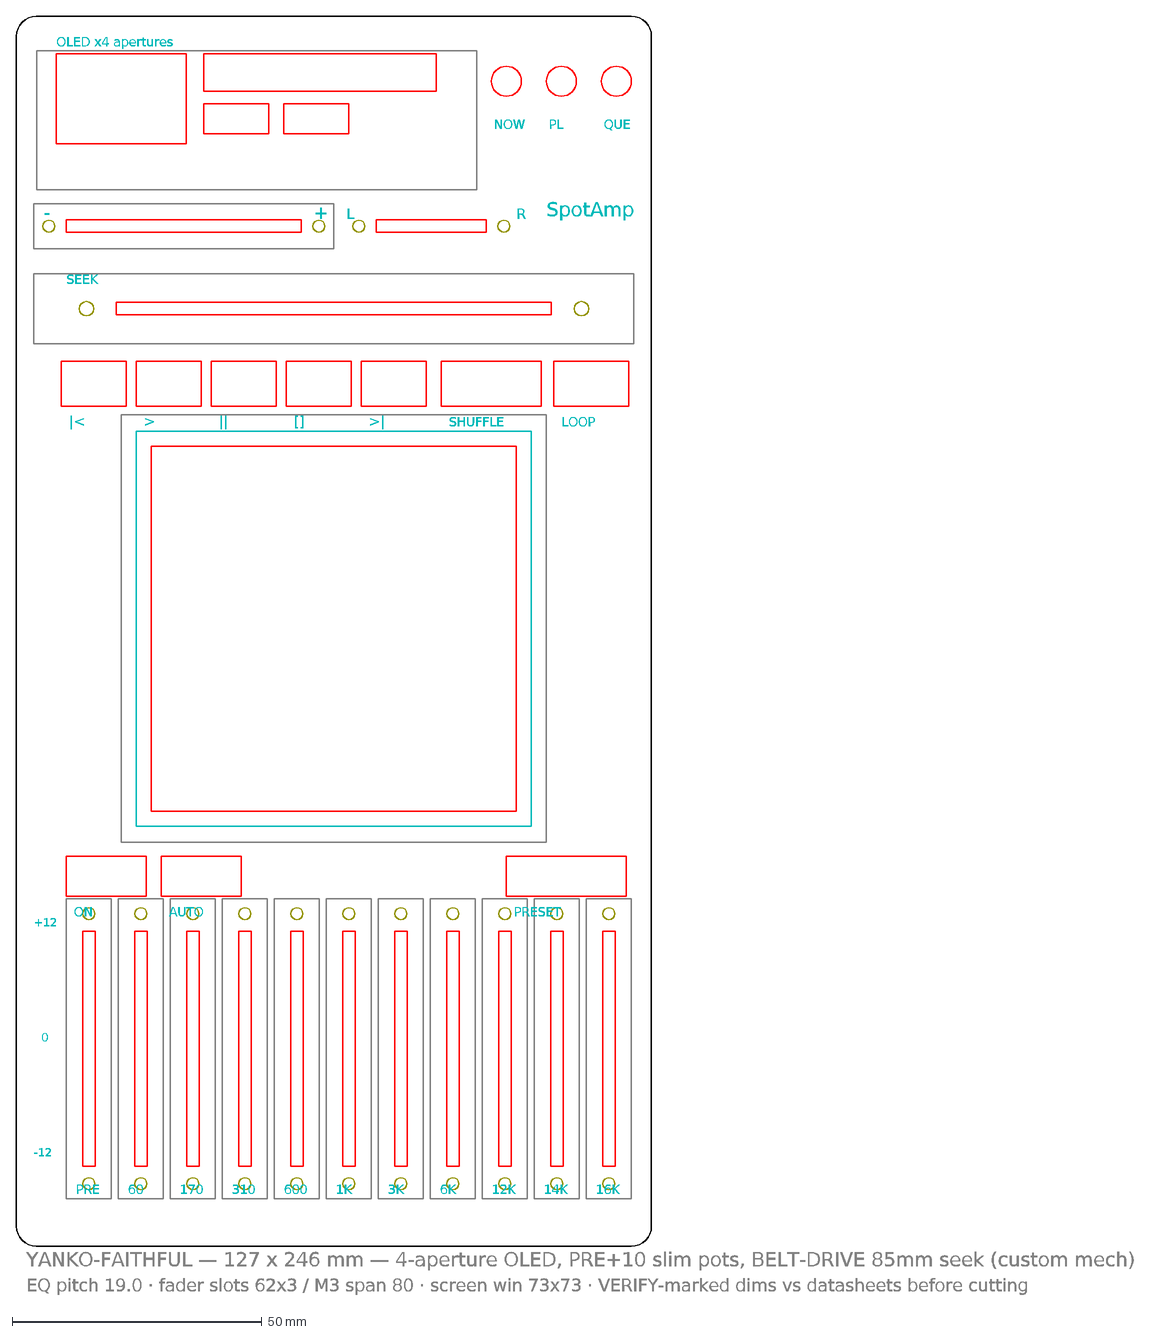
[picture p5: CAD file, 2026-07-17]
hardware/cad/front-panel-final.dxf
OLED x4 apertures
NOW
PL
QUE
-
+
L
R
SpotAmp
SEEK
|<
>
||
[]
>|
SHUFFLE
LOOP
ON
AUTO
PRESET
+12
0
-12
PRE
60
170
310
600
1K
3K
6K
12K
14K
16K
YANKO-FAITHFUL — 127 x 246 mm — 4-aperture OLED, PRE+10 slim pots, BELT-DRIVE 85mm seek (custom mech)
EQ pitch 19.0 · fader slots 62x3 / M3 span 80 · screen win 73x73 · VERIFY-marked dims vs datasheets before cutting

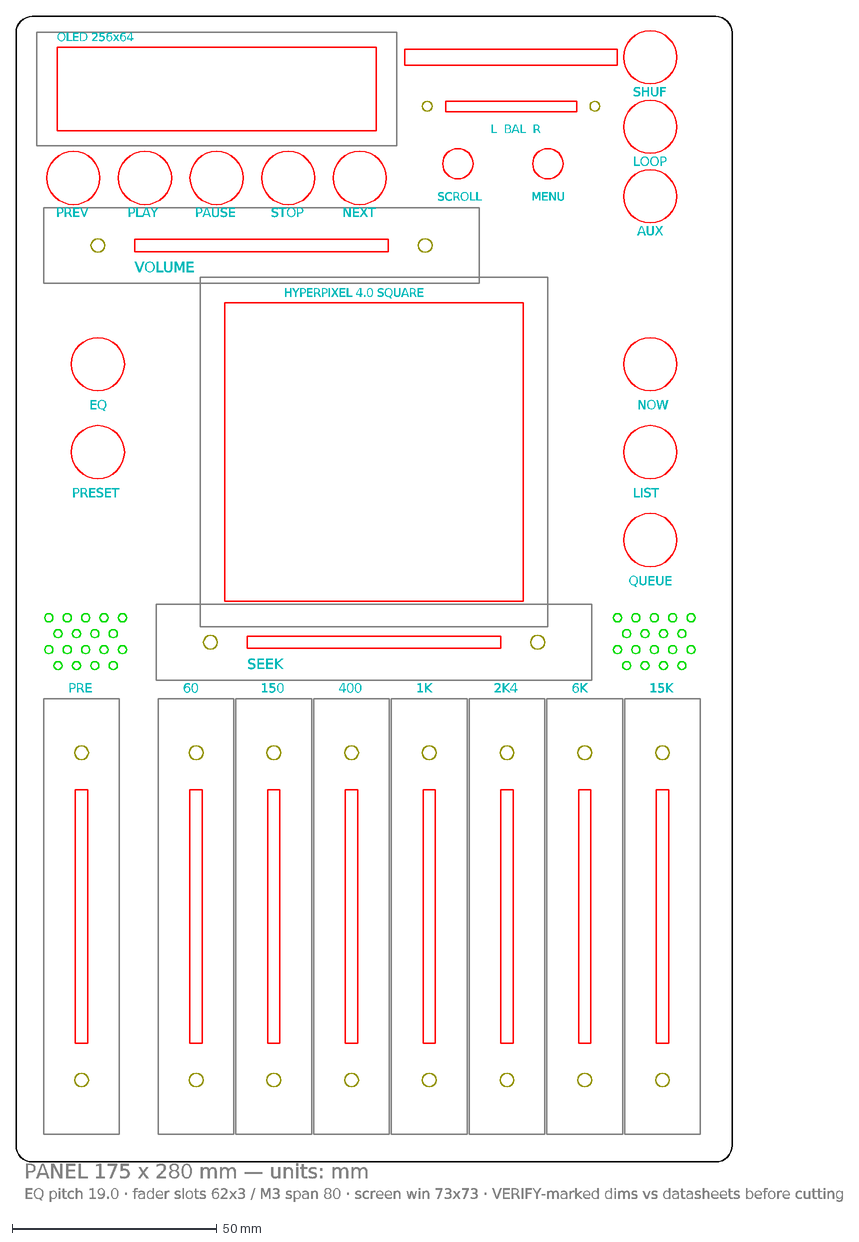
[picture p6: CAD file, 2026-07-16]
hardware/cad/front-panel.dxf
OLED 256x64
L BAL R
SCROLL
MENU
SHUF
LOOP
AUX
PREV
PLAY
PAUSE
STOP
NEXT
VOLUME
HYPERPIXEL 4.0 SQUARE
NOW
LIST
QUEUE
EQ
PRESET
SEEK
PRE
60
150
400
1K
2K4
6K
15K
PANEL 175 x 280 mm — units: mm
EQ pitch 19.0 · fader slots 62x3 / M3 span 80 · screen win 73x73 · VERIFY-marked dims vs datasheets before cutting

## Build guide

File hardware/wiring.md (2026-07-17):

# Wiring & physical layout

## Schematics

| Diagram | What it shows |
|---|---|
| [**System wiring**](diagrams/system-wiring.svg) | Full power + data topology: battery → UPS → Pi/motor rail; USB to the RP2040 + DAC; the I2C expander bus (PCA9685/MPR121/MCP23017) out to the faders |
| [**Pico pinout**](diagrams/pico-pinout.svg) | Every RP2040 pin assignment (19 of 26 used, spares marked) |
| [**Front panel (authoritative)**](cad/) | The dimensioned cut drawing — `cad/front-panel.dxf` / `.svg` |

System wiring

Pico pinout

Front panel

> ⚠️ **Dimension findings** (ALPS datasheet + the dimensioned cut drawing):
> fader bodies are **18.5 mm wide × 26 mm deep × 106.5 mm long (M3 span 80 mm)**.
> The 8-fader bank therefore needs ~155 mm of width and **~110 mm of height** —
> honest envelope: **175 × 280 × 32 mm (6.9″ × 11″ × 1.25″)**, proven with real
> clearances in **[cad/front-panel.dxf](cad/)** (the authoritative drawing).
> Full analysis + the compact fallback: [enclosure.md](enclosure.md).

## Front-panel layout (ASCII summary — superseded by cad/, kept for orientation)

Mirrors the software's regions so the code and the hardware agree:

```
┌───────────────────────────────────────────┐  ← ~127 mm wide
│  SPOTAMP       (title)   │
├───────────────────────────────────────────┤
│  0:42   [ amber OLED readout ]   320 kbps  │   PHYSICAL panel
│  ░░▓▓██▓░ title + spectrum       44 kHz    │   SSD1322 256×64 SPI OLED on the
│  |◀ ▶ ▮▮ ■ ▶| SHUF LOOP PRESET [==BAL==]   │   RP2040 (`DISP` commands) +
│  [====VOL (motorized)====]                 │   buttons + balance pot + volume
├───────────────────────────────────────────┤
│  [NP] [PL] [Q]  (view-switch buttons)     │   PHYSICAL (ButtonId 9–11)
│   ┌─────────────────────────────┐         │
│   │                             │         │   SCREEN
│   │   HyperPixel 4.0 Square     │         │   720×720 DPI touchscreen
│   │   (multi-view UI: now       │         │   ⚠ occupies ALL 40 GPIO —
│   │   playing/playlists/queue)  │         │   controls/battery on RP2040,
│   └─────────────────────────────┘         │   audio via USB DAC
│                                           │
├───────────────────────────────────────────┤
│  EQ:  ▮ ▮ ▮ ▮ ▮ ▮ ▮   ▮(pre)              │   PHYSICAL panel
│      60 150 400 1k 2k4 6k 15k              │   8 motorized 60 mm faders
├───────────────────────────────────────────┤
│  [====VOL====]      [====SEEK====]         │   2 motorized faders (horizontal)
└───────────────────────────────────────────┘
```

## Pico (RP2040) pin plan — expander architecture

**Direct-wiring does not fit**: 10 motors × 2 PWM + 10 touch + 13 buttons +
mux + encoders ≈ **55 signals vs the Pico's 26 GPIO**. Everything high-count
rides one I2C bus instead:

```
                        ┌── PCA9685 #1 ──▶ DRV8833 ×3 ──▶ fader motors 0–5
                        ├── PCA9685 #2 ──▶ DRV8833 ×2 ──▶ fader motors 6–9
Pico I2C (2 pins) ──────┼── MPR121  ──▶ 10 fader touch-sense lines
                        ├── MCP23017 ──▶ 13 panel buttons + headphone-jack detect
                        └── TPA2016 amp ──▶ internal stereo speakers (gain/AGC/mute)
```

| Function | Pico pins | Count |
|---|---|---|
| I2C bus (PCA9685 ×2, MPR121, MCP23017, TPA2016) | GP4/GP5 | 2 |
| Mux (CD74HC4067) select S0–S3 | GP6–GP9 | 4 |
| Mux common out → ADC (wipers + balance pot) | GP26 (ADC0) | 1 |
| OLED readout (SSD1322, SPI + DC/CS/RST) | GP10–GP14 | 5 |
| Encoders (EC11) ×2 + push | GP16–GP21 | 6 |
| WS2812 LEDs | GP22 (PIO) | 1 |
| USB | to Pi (CDC serial + power) | — |
| **Total** | | **19 of 26** ✅ |

Each motorized fader needs **three** connections handled together:
1. **Motor** → a DRV8833 channel, its two inputs driven by PCA9685 outputs.
2. **Wiper** → a mux input → ADC, for the PID's position feedback.
3. **Touch** → an MPR121 electrode, so the Pi knows to stop driving it.

> **PWM-frequency caveat:** the PCA9685 tops out at ~1.5 kHz, which is audible as
> a faint buzz *while a fader is moving*. Moves last well under a second, and the
> **reduced build** (only volume + seek motorized, driven directly from Pico PWM
> pins at 20 kHz+) sidesteps it completely.

## Electrical detail notes (desk-verified against datasheets, 2026-07-16)

**I2C address map** — no conflicts ✓:

| Device | Addr | Note |
|---|---|---|
| PCA9685 #1 | 0x40 | default |
| PCA9685 #2 | 0x41 | solder jumper A0 |
| MCP23017 | 0x20 | A0–A2 → GND |
| X728 fuel gauge (MAX17040) | 0x36 | see battery note below |
| TPA2016 amp | 0x58 | fixed |
| MPR121 | 0x5A | ADDR → GND |

- **Pull-ups**: every breakout ships its own (typ. 10 k). Six in parallel ≈ 1.7 k —
  near the 3 mA sink limit. If the bus misbehaves, desolder pull-ups from all but
  one board.
- **Motor-safe boot**: PCA9685 outputs are indeterminate until configured — tie
  both boards' **/OE to GP3 with a pull-up** so motors stay disabled until the
  firmware releases them. (GP3 was spare.)
- **Simultaneous-slew current**: stagger the PCA9685 per-channel ON offsets so 10
  motors don't switch in phase; with the 2× 2200 µF bulk caps that tames rail sag.
- **Touch-sense wiring**: each fader's T terminal → an MPR121 electrode. Keep the
  runs short and away from the motor leads (they're capacitive sense lines).

**Mux channel map** (CD74HC4067 → ADC0):

| CH | Signal |
|---|---|
| 0–6 | EQ band wipers 0–6 |
| 7 | preamp wiper |
| 8 | volume wiper |
| 9 | seek wiper |
| 10 | balance pot |
| 11–15 | spare |

**Battery telemetry** — the X728 can't stack on the Pi (HyperPixel owns the
header); it runs beside it and powers the Pi over USB-C. Its **MAX17040 fuel
gauge is I2C** — so jumper the X728 header's SDA/SCL/GND over to the **RP2040
bus** (addr 0x36, no conflict) and the firmware reports real state-of-charge over
serial (`power.py` already knows the MAX17040 registers). X728's AC-loss/PLD
signal → **GP2** (was spare) for charge-state. Fallback if the jumpering fights
us: a resistor divider off the battery to **GP28/ADC2** (for a 1S pack, 4.2 V max:
39 k / 100 k → 3.0 V full-scale — **verify the X728's cell topology first**).

## Control loop (firmware)

Per motorized fader, ~1 kHz:

```
error = target - read_position(fader)
if touched(fader):        # user wins
    motor_off(fader); report EV FADER when it settles
else:
    drive = PID(error)    # tune Kp/Ki/Kd per fader
    motor_pwm(fader, clamp(drive))
```

See `firmware/src/main.cpp` for the skeleton.

## Power & audio

- LiPo → power board (5 V boost) → Pi 4; motors get their own regulated rail off
  the same pack (H-bridges draw spikes — decouple well, keep motor ground and
  logic ground joined at one star point).
- **USB DAC** on a Pi USB port (the HyperPixel's DPI takes the I2S pins, so no
  GPIO DAC) → line out → **switched headphone jack** → **TPA2016 stereo amp** →
  internal enclosed speakers. Headphone insertion is sensed (MCP23017 input) and
  firmware mutes the amp over I2C. Pi USB budget: RP2040 + DAC = 2 of 4 ports.
- External outputs are **software**: Spotify Connect transfer for Sonos/Connect
  gear (Web API `transfer_to`), and BT A2DP via the Pi 4's onboard Bluetooth.

## Enclosure

- Book form, ~200 × 127 × 25 mm. Faders and their travel set the depth — 60 mm
  faders + motor bodies are the tallest components; plan ~20 mm behind the panel.
- Print the front panel with slots for fader travel and cutouts for the LCD,
  buttons, and encoders. A kickstand echoes the Yanko concept's EQ-base stand.
- CAD lives here later (`hardware/cad/`), source + STL.

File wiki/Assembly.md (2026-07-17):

# Assembly

> **Placeholder** — wiring reference: [hardware/wiring.md](https://github.com/Paco5687/SpotAmp/blob/main/hardware/wiring.md)

To be written up as the physical build comes together. Planned sections:

- [ ] Front-panel layout (portrait, 175 × 280 mm) and cutouts — see hardware/cad/
- [ ] RP2040 pin map, mux wiring, motor-driver hookup
- [ ] Motorized fader wiring (motor / wiper / touch), one per fader
- [ ] Pi 4 B + DSI LCD + I2S DAC stack
- [ ] Power: UPS HAT + cells + bulk caps + switch (see [Power and Battery](Power-and-Battery))
- [ ] 3D-printed enclosure (STLs + source) — *to be published with the finished build*
- [ ] Photos + step-by-step

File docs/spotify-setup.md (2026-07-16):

# Spotify setup — fully standalone (no phone)

The device authenticates to Spotify **by itself**. No phone, no companion app in
the loop — just a network connection and a Spotify **Premium** account. There
are two one-time browser authorizations during setup; after that the device
runs autonomously and reconnects on cached credentials forever.

```
                       ONE-TIME SETUP                         EVERY BOOT AFTER
  ┌────────────────────────────────────────┐      ┌───────────────────────────┐
  │ 1. go-librespot interactive OAuth       │      │ go-librespot reconnects   │
  │    → caches credentials.json            │ ───▶ │  (cached creds)           │
  │ 2. Web API PKCE (authorize.py)          │      │ app lists YOUR playlists  │
  │    → caches spotify_token.json          │      │ tap one → it plays        │
  └────────────────────────────────────────┘      └───────────────────────────┘
        (browser once — Pi screen or laptop)              (no phone, ever)
```

Why two logins? They're two different jobs:

| | **go-librespot** | **Web API** (`spotify_web.py`) |
|---|---|---|
| Job | Streams + decodes the actual audio | Lists playlists, album art, "play this" |
| Auth | Interactive OAuth → `credentials.json` | PKCE → `spotify_token.json` |
| Needs Premium | ✅ | (uses same account) |
| Needs a phone | ❌ | ❌ |

---

## 1. go-librespot (the audio engine)

Install go-librespot on the Pi (see its
[README](https://github.com/devgianlu/go-librespot) for the current binary/build
steps), then configure it for standalone interactive login.

`~/.config/go-librespot/config.yml` (representative — verify key names against
the go-librespot README, which is the source of truth):

```yaml
device_name: "SpotAmp"
device_type: computer

credentials:
  type: interactive          # one-time browser OAuth, then cached — NOT zeroconf

audio_backend: alsa          # on the Pi; routes into our EQ chain → I2S DAC

server:                      # the HTTP/WebSocket API our app talks to
  enabled: true
  address: 127.0.0.1
  port: 3678
```

First run does the login:

```bash
go-librespot            # prints an auth URL; approve in a browser, once
```

- If you run it **on the Pi** (touchscreen browser), the loopback callback closes
  the loop right there.
- If you run it **on a laptop** first, copy the resulting `credentials.json` from
  `~/.config/go-librespot/` to the same path on the Pi.

After this, it reconnects headless on every boot. Point our app at it with
`backend = "librespot"` and `librespot_url = "http://127.0.0.1:3678"` in
`config.toml`.

## 2. Web API (browse + control)

This is the flow already built into the app:

1. Create an app at https://developer.spotify.com/dashboard.
2. Add redirect URI **exactly**: `http://127.0.0.1:8888/callback`
3. Put the **Client ID** in `pi/config.toml` (`spotify_client_id`). No secret — PKCE.
4. `python -m spotamp.authorize` → approve once → `spotify_token.json` cached.

See [../pi/README.md](../pi/README.md#connect-spotify-web-api--playlists--album-art).

---

## Do we even need the Web API to *start* playback?

Not strictly — go-librespot's own HTTP API can start a context (playlist/album)
URI and reports now-playing metadata + album art. But the Web API is what lets us
**browse your whole playlist library** on the touchscreen (go-librespot can't list
your playlists). So: **browse via Web API, play via librespot.** Both authorized
standalone, both cached, no phone.

## Caveats (the honest ones)

- **Premium required** — librespot won't stream on free accounts.
- **One browser step per login, once.** Spotify removed password auth, so the
  initial OAuth can't be fully headless — but it's a setup-time cost only.
- **librespot is unofficial** (reverse-engineered). Reliable and widely used, but
  not sanctioned by Spotify.

## Development Mode limitation (Feb 2026 migration)

Spotify's Feb 2026 Web API change (enforced 2026-03-09) means a **Development
Mode** app can only read the **tracks** of playlists you **own or collaborate
on**. For Spotify-owned/editorial playlists (Discover Weekly, Daily Mix, "Today's
Top Hits", etc.) the Web API returns metadata only — the UI flags these as
*"dev-mode locked."* Also note: `GET /playlists/{id}/tracks` was removed; use
`GET /playlists/{id}/items` (track field renamed `track` → `item`).

**Important nuance:** this only limits *reading a track list* over the Web API.
It does **not** limit **playback** — go-librespot can play *any* playlist by its
context URI, and reports now-playing metadata itself. So on the real device we
can still play editorial playlists; we just show now-playing from librespot
instead of a pre-fetched track list. Getting full track-list access for all
playlists would require Spotify **Extended Quota Mode** (a manual approval), which
isn't worth it for a personal build.

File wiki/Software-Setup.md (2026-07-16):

# Software Setup

> **Placeholder** — see [pi/README.md](https://github.com/Paco5687/SpotAmp/blob/main/pi/README.md).

## Try the UI on a laptop (no hardware)
```bash
cd pi
pip install -r requirements.txt
python -m spotamp
```
Requires Python 3.11+. Opens the WinAmp-style UI with a demo playlist.

## On the Raspberry Pi 4 B

The full, tested procedure lives in
**[docs/pi-bringup.md](https://github.com/Paco5687/SpotAmp/blob/main/docs/pi-bringup.md)**:

1. Flash Raspberry Pi OS (64-bit, Desktop); enable SSH.
2. Install [go-librespot](https://github.com/devgianlu/go-librespot) (audio) as a
   systemd service; one-time standalone OAuth ([Spotify Setup](Spotify-Setup)).
3. HyperPixel 4.0 Square display: **disable I2C/SPI** (DPI uses all GPIO), add the
   `vc4-kms-dpi-hyperpixel4sq` overlay; rotate at the compositor level.
4. Clone the repo, `pip install -r pi/requirements.txt` in a venv, copy
   `config.example.toml` → `config.toml` (`backend = "librespot"`).
5. Kiosk autostart via the systemd user service in `deploy/` — boots straight
   into the UI. Audio: 3.5 mm jack for bring-up, USB DAC for the real build.
6. Later: flash the [Firmware](Firmware) to the RP2040 for physical controls.

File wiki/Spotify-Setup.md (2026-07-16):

# Spotify Setup

> **Placeholder** — full guide: [docs/spotify-setup.md](https://github.com/Paco5687/SpotAmp/blob/main/docs/spotify-setup.md)

Fully **standalone** — network + a Spotify **Premium** account, **no phone**.
Two one-time browser logins, both loopback (no website/hosting):

1. **go-librespot** (audio) — interactive OAuth → caches `credentials.json`.
2. **Web API** (browse/control) — PKCE → `python -m spotamp.authorize`.
   Register redirect URI `http://127.0.0.1:8888/callback` in the Spotify dashboard.

Notes:
- Add your account under **User Management** in the Spotify dashboard (Dev Mode).
- Dev Mode can't read the *tracklist* of playlists you don't own, but you can
  still **play** any followed/editorial playlist.

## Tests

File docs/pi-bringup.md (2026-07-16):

# Raspberry Pi bring-up (standalone player)

The exact, reproducible steps to turn a fresh Pi 4 B into the standalone player:
go-librespot for audio + the SpotAmp app on the screen. Written from a real
bring-up on 2026-07-15 (Raspberry Pi OS Bookworm, 64-bit).

## 1. Flash + first boot

- **Raspberry Pi OS (64-bit), Desktop**, via Raspberry Pi Imager.
- In the Imager gear: set hostname (`spotamp`), **enable SSH**, username, Wi-Fi, locale.
- First boot:
  ```bash
  sudo apt update && sudo apt full-upgrade -y
  sudo raspi-config   # Interface: enable I2C, SPI, Serial
  sudo reboot
  ```

## 2. go-librespot (the audio engine)

```bash
sudo apt-get install -y libogg-dev libvorbis-dev libflac-dev libasound2-dev curl
mkdir -p ~/go-librespot && cd ~/go-librespot
URL=$(curl -s https://api.github.com/repos/devgianlu/go-librespot/releases/latest \
      | grep -o 'https://[^"]*linux_arm64[^"]*\.tar\.gz' | head -1)
curl -L "$URL" -o go-librespot.tar.gz && tar xzf go-librespot.tar.gz && chmod +x go-librespot
```

Config `~/.config/go-librespot/config.yml` (see [../config/go-librespot.example.yaml](../config/go-librespot.example.yaml)):
```yaml
device_name: "SpotAmp"
device_type: computer
audio_backend: alsa
audio_device: plughw:CARD=Headphones   # Pi 3.5mm jack; USB DAC on the real build
credentials:
  type: interactive
server:
  enabled: true
  address: localhost
  port: 3678
```

### Headless OAuth (no browser on the Pi)

1. `cd ~/go-librespot && ./go-librespot` — prints an `accounts.spotify.com/authorize?...` URL.
2. Open that URL in a browser **on another machine**, authorize.
3. It redirects to `http://127.0.0.1:<PORT>/login?code=…` which won't load — **copy that URL**.
4. In a second SSH session on the Pi: `curl "http://127.0.0.1:<PORT>/login?code=…"`.
5. go-librespot logs in and caches `credentials.json` — standalone from now on.

### Audio device

`aplay -l` lists the cards; the 3.5mm jack is `bcm2835 Headphones` (card 2 here), so
`audio_device: plughw:CARD=Headphones`. `raspi-config`'s audio default does **not**
affect go-librespot's ALSA path — set the device explicitly. If silent, `alsamixer`
(F6 → the card → unmute `M`, raise volume). *The final build uses a USB DAC (issue #12).*

### Run as a service (auto-start on boot)

Install [../deploy/go-librespot.service](../deploy/go-librespot.service):
```bash
sudo cp ~/SpotAmp/deploy/go-librespot.service /etc/systemd/system/
sudo systemctl daemon-reload && sudo systemctl enable --now go-librespot
journalctl -u go-librespot -f
```

**Standalone check:** `curl -X POST http://localhost:3678/player/play -H 'Content-Type: application/json' -d '{"uri":"spotify:playlist:37i9dQZF1DXcBWIGoYBM5M"}'` — music plays with no phone/Spotify app open.

## 3. The SpotAmp app

```bash
cd ~ && git clone https://github.com/Paco5687/SpotAmp.git
cd SpotAmp/pi
python3 -m venv venv && source venv/bin/activate
pip install -r requirements.txt          # piwheels provides arm64 pygame
cp config.example.toml config.toml       # set backend="librespot", controls="mock"
SDL_VIDEODRIVER=dummy python -c "import spotamp.app; print('ok')"   # sanity
```

### Run on the display (labwc / Wayland)

The Pygame app needs the Pi's Wayland session (not SSH). Launch it onto the session:
```bash
export XDG_RUNTIME_DIR=/run/user/1000 DBUS_SESSION_BUS_ADDRESS=unix:path=/run/user/1000/bus
systemd-run --user --unit=spotamp-ui \
  --setenv=WAYLAND_DISPLAY=wayland-0 --setenv=SDL_VIDEODRIVER=wayland \
  --working-directory=$HOME/SpotAmp/pi \
  $HOME/SpotAmp/pi/venv/bin/python -m spotamp
```
## 4. HyperPixel 4.0 Square + kiosk autostart

The real display is a **Pimoroni HyperPixel 4.0 Square (720×720, DPI)**. DPI uses
all 40 GPIO, so disable the GPIO interfaces first, then add the overlay:

```bash
sudo raspi-config nonint do_i2c 1   # DPI needs the I2C/SPI GPIO
sudo raspi-config nonint do_spi 1
echo "dtoverlay=vc4-kms-dpi-hyperpixel4sq" | sudo tee -a /boot/firmware/config.txt
sudo reboot
```

After reboot the panel is output `DPI-1` at 720×720. **Don't** rotate with the
overlay's `rotate=` — that flips the display at the KMS level but *not the touch
matrix*. Rotate at the **compositor** level instead (moves display + touch
together) — the kiosk launcher does this with `wlr-randr --output DPI-1
--transform 180`.

### Kiosk autostart (boots straight into the UI)

Use the files in [`../deploy/`](../deploy/):

```bash
mkdir -p ~/.config/systemd/user
cp ~/SpotAmp/deploy/spotamp-kiosk.service ~/.config/systemd/user/
cp ~/SpotAmp/deploy/spotamp-kiosk.sh ~/.config/spotamp-kiosk.sh
chmod +x ~/.config/spotamp-kiosk.sh
sudo loginctl enable-linger "$USER"       # user manager starts at boot
systemctl --user daemon-reload
systemctl --user enable --now spotamp-kiosk.service
```

Set `fullscreen = true` in `config.toml` (fills the 720×720 panel and hides the
cursor). The launcher waits for the Wayland socket, so it's robust to boot timing;
`Restart=on-failure` keeps it up, while a clean `q`/Esc still exits.

> RPi's labwc runs the *system* autostart and ignores `~/.config/labwc/autostart`;
> the XDG `.desktop` route was flaky on boot too. A **systemd user service** is the
> reliable path here.

## 5. Remote control from a laptop (optional, dev)

Add the laptop's SSH public key to the Pi's `~/.ssh/authorized_keys` for passwordless
`ssh bkern@spotamp.local` — handy for deploying/logging without a keyboard on the Pi.

> ⚠️ Gotcha: don't `pkill -f "python -m spotamp"` over SSH — the pattern matches
> the SSH command's own command line and kills your session. Use
> `systemctl --user stop spotamp-ui` instead.

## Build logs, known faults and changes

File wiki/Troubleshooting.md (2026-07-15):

# Troubleshooting

> **Placeholder** — to grow as issues surface.

## Spotify
- **403 on `/v1/me`** → add your account under Dashboard → **User Management** (Dev Mode allowlist).
- **403 on playlist tracks** → expected for playlists you don't own (Feb-2026 Dev Mode rule); you can still *play* them with `backend = "webapi"`.
- **"No active Spotify device"** → open the Spotify app or start go-librespot so there's a device to play on.

## App
- **`[library] …` in console** → the browser fell back to the demo list; the message says why.
- Album art stays a gradient → the image is still downloading, or JPEG decode is unavailable in your pygame build.

## Hardware
- Fader oscillates/hunts → tune the PID gains (start low `Kp`, add `Kd`).
- Audio whine → separate motor-current wiring from the DAC lines; check grounding.
- Random reboots under load → 5 V rail sagging on motor spikes; add bulk caps (see [Power and Battery](Power-and-Battery)).

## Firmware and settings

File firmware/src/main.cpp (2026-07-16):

// SpotAmp — RP2040 controls firmware.
//
// Implements the full serial protocol (docs/serial-protocol.md) over USB CDC:
//   in : FADER, FADER_RELEASE, LED, DISP TITLE/TIME/INFO, PING
//   out: EV BTN/FADER/TOUCH/ENC/POT/BAT/CHG/JACK, PONG, LOG
//
// I/O architecture (hardware/wiring.md): motors via 2x PCA9685 -> DRV8833,
// touch via MPR121, buttons via MCP23017, amp via TPA2016, battery via the
// X728's MAX17040 — all on one I2C bus. OLED readout on software SPI.
// Written desk-first (2026-07-16): compiles clean; PID gains + stiction floor
// need bench tuning with real faders.

#include <Arduino.h>
#include <Wire.h>

#include "config.h"

#if HAS_PCA9685
#include <Adafruit_PWMServoDriver.h>
#endif
#if HAS_MPR121
#include <Adafruit_MPR121.h>
#endif
#if HAS_MCP23017
#include <Adafruit_MCP23X17.h>
#endif
#if HAS_TPA2016
#include <Adafruit_TPA2016.h>
#endif
#if HAS_NEOPIXEL
#include <Adafruit_NeoPixel.h>
#endif
#if HAS_OLED
#include <U8g2lib.h>
#endif

// --------------------------------------------------------------------------- //
// devices (presence-flagged so a missing board degrades, never hangs)
// --------------------------------------------------------------------------- //
#if HAS_PCA9685
Adafruit_PWMServoDriver pcaA(ADDR_PCA_A);
Adafruit_PWMServoDriver pcaB(ADDR_PCA_B);
bool havePcaA = false, havePcaB = false;
#endif
#if HAS_MPR121
Adafruit_MPR121 touch;
bool haveTouch = false;
#endif
#if HAS_MCP23017
Adafruit_MCP23X17 mcp;
bool haveMcp = false;
#endif
#if HAS_TPA2016
Adafruit_TPA2016 amp;
bool haveAmp = false;
#endif
#if HAS_NEOPIXEL
Adafruit_NeoPixel pixels(NUM_PIXELS, PIN_NEOPIXEL, NEO_GRB + NEO_KHZ800);
#endif
#if HAS_OLED
U8G2_SSD1322_NHD_256X64_F_4W_SW_SPI oled(U8G2_R0, PIN_OLED_SCK, PIN_OLED_MOSI,
                                         PIN_OLED_CS, PIN_OLED_DC, PIN_OLED_RST);
bool haveOled = false;
#endif

// --------------------------------------------------------------------------- //
// state
// --------------------------------------------------------------------------- //
struct Fader {
  int16_t  target = -1;        // -1 = released (user owns it)
  float    pos = 0;            // filtered position, 0..1023
  float    prevErr = 0;
  bool     touched = false;
  uint16_t lastReported = 0xFFFF;
};
Fader faders[NUM_FADERS];

uint16_t balanceLast = 0xFFFF;
uint16_t buttonsLast = 0xFFFF;   // MCP GPIOAB snapshot (pull-ups: 1 = released)
uint32_t buttonsChangedAt[16] = {0};
bool     jackLast = false;

int8_t  encAccum[2] = {0, 0};
uint8_t encPrev[2] = {0, 0};
bool    encSwLast[2] = {true, true};

char  dispTitle[96] = "SPOTAMP";
uint32_t dispPosMs = 0, dispDurMs = 0;
uint16_t dispKbps = 0, dispKhz = 0;
uint32_t dispPosStamp = 0;       // millis() when dispPosMs was set
int16_t  marqueeX = 0;

// --------------------------------------------------------------------------- //
// serial protocol
// --------------------------------------------------------------------------- //
static void emit(const char* type, int id, long value) {
  Serial.print("EV "); Serial.print(type); Serial.print(' ');
  Serial.print(id); Serial.print(' '); Serial.println(value);
}
static void logmsg(const char* msg) { Serial.print("LOG "); Serial.println(msg); }

static char rxBuf[160];
static uint8_t rxLen = 0;

static void handleDisp(char* args) {
  char* what = strtok(args, " ");
  if (!what) return;
  if (!strcmp(what, "TITLE")) {
    char* rest = strtok(nullptr, "");            // remainder incl. spaces
    strncpy(dispTitle, rest ? rest : "-", sizeof(dispTitle) - 1);
    dispTitle[sizeof(dispTitle) - 1] = 0;
    marqueeX = 0;
  } else if (!strcmp(what, "TIME")) {
    dispPosMs = strtoul(strtok(nullptr, " ") ?: "0", nullptr, 10);
    dispDurMs = strtoul(strtok(nullptr, " ") ?: "0", nullptr, 10);
    dispPosStamp = millis();
  } else if (!strcmp(what, "INFO")) {
    dispKbps = atoi(strtok(nullptr, " ") ?: "0");
    dispKhz  = atoi(strtok(nullptr, " ") ?: "0");
  }
}

static void handleCommand(char* line) {
  char* verb = strtok(line, " ");
  if (!verb) return;
  if (!strcmp(verb, "PING")) {
    Serial.println("PONG");
  } else if (!strcmp(verb, "FADER")) {
    int id = atoi(strtok(nullptr, " ") ?: "-1");
    int pos = atoi(strtok(nullptr, " ") ?: "0");
    if (id >= 0 && id < NUM_FADERS)
      faders[id].target = constrain(pos, 0, (int)FADER_MAX);
  } else if (!strcmp(verb, "FADER_RELEASE")) {
    int id = atoi(strtok(nullptr, " ") ?: "-1");
    if (id >= 0 && id < NUM_FADERS) faders[id].target = -1;
  } else if (!strcmp(verb, "LED")) {
#if HAS_NEOPIXEL
    int i = atoi(strtok(nullptr, " ") ?: "0");
    int r = atoi(strtok(nullptr, " ") ?: "0");
    int g = atoi(strtok(nullptr, " ") ?: "0");
    int b = atoi(strtok(nullptr, " ") ?: "0");
    if (i >= 0 && i < (int)NUM_PIXELS) {
      pixels.setPixelColor(i, pixels.Color(r, g, b));
      pixels.show();
    }
#endif
  } else if (!strcmp(verb, "DISP")) {
    handleDisp(strtok(nullptr, ""));
  }
}

static void pollSerial() {
  while (Serial.available()) {
    char c = (char)Serial.read();
    if (c == '\n' || c == '\r') {
      if (rxLen) { rxBuf[rxLen] = 0; handleCommand(rxBuf); rxLen = 0; }
    } else if (rxLen < sizeof(rxBuf) - 1) {
      rxBuf[rxLen++] = c;
    } else {
      rxLen = 0;  // overlong line: drop it
    }
  }
}

// --------------------------------------------------------------------------- //
// analog mux
// --------------------------------------------------------------------------- //
static uint16_t readMux(uint8_t channel) {
  for (uint8_t i = 0; i < 4; i++) digitalWrite(PIN_MUX_S[i], (channel >> i) & 1);
  delayMicroseconds(8);                 // mux + RC settle
  return analogRead(PIN_MUX_ADC);       // 10-bit, 0..1023
}

// --------------------------------------------------------------------------- //
// motors (PCA9685 -> DRV8833). Fader f uses channels f*2 / f*2+1.
// --------------------------------------------------------------------------- //
static void motorRaw(uint8_t f, uint16_t in1, uint16_t in2) {
#if HAS_PCA9685
  uint8_t chan = (f * 2) % 16;
  Adafruit_PWMServoDriver* p = (f < 8) ? &pcaA : &pcaB;
  bool have = (f < 8) ? havePcaA : havePcaB;
  if (!have) return;
  p->setPin(chan, in1, false);
  p->setPin(chan + 1, in2, false);
#endif
}
static void motorOff(uint8_t f) { motorRaw(f, 0, 0); }  // coast

static void motorDrive(uint8_t f, float effort) {
  // effort in [-1, 1]; map through the stiction floor so small efforts move.
  if (effort == 0) { motorOff(f); return; }
  uint16_t mag = (uint16_t)(PWM_MIN_MOVE + fabsf(effort) * (PWM_MAX - PWM_MIN_MOVE));
  if (mag > PWM_MAX) mag = PWM_MAX;
  if (effort > 0) motorRaw(f, mag, 0);
  else            motorRaw(f, 0, mag);
}

// --------------------------------------------------------------------------- //
// subsystem tasks
// --------------------------------------------------------------------------- //
static void taskControl() {           // PID_HZ
  static const float dt = 1.0f / PID_HZ;
  for (uint8_t f = 0; f < NUM_FADERS; f++) {
    uint16_t raw = readMux(f);
    Fader& fd = faders[f];
    fd.pos += 0.5f * ((float)raw - fd.pos);        // light EMA filter

    if (fd.touched || fd.target < 0) {
      motorOff(f);
      uint16_t p = (uint16_t)fd.pos;
      if (abs((int)p - (int)fd.lastReported) > REPORT_DELTA) {
        emit("FADER", f, p);
        fd.lastReported = p;
      }
      fd.prevErr = 0;
      continue;
    }
    float err = (float)fd.target - fd.pos;
    if (fabsf(err) <= PID_DEADBAND) { motorOff(f); fd.prevErr = 0; continue; }
    float deriv = (err - fd.prevErr) / dt;
    fd.prevErr = err;
    float effort = (PID_KP * err + PID_KD * deriv) / (float)FADER_MAX;
    motorDrive(f, constrain(effort, -1.0f, 1.0f));
  }
  // balance pot
  uint16_t bal = readMux(MUX_CH_BALANCE);
  if (balanceLast == 0xFFFF || abs((int)bal - (int)balanceLast) > REPORT_DELTA) {
    emit("POT", 0, bal);
    balanceLast = bal;
  }
}

static void taskTouch() {             // ~100 Hz
#if HAS_MPR121
  if (!haveTouch) return;
  uint16_t t = touch.touched();
  for (uint8_t f = 0; f < NUM_FADERS; f++) {
    bool now = t & (1u << f);
    if (now != faders[f].touched) {
      faders[f].touched = now;
      if (now) motorOff(f);
      emit("TOUCH", f, now ? 1 : 0);
    }
  }
#endif
}

static void taskButtons() {           // ~200 Hz, 8 ms debounce
#if HAS_MCP23017
  if (!haveMcp) return;
  uint16_t gpio = mcp.readGPIOAB();
  uint32_t now = millis();
  if (buttonsLast == 0xFFFF) { buttonsLast = gpio; return; }
  for (uint8_t i = 0; i <= NUM_BUTTONS; i++) {   // 0-12 buttons; 15 = jack below
    if (i >= 16) break;
    bool was = !(buttonsLast & (1u << i));       // active-low (pull-ups)
    bool is  = !(gpio & (1u << i));
    if (was != is && now - buttonsChangedAt[i] > 8) {
      buttonsChangedAt[i] = now;
      if (i < NUM_BUTTONS) emit("BTN", i, is ? 1 : 0);
    }
  }
  bool jack = !(gpio & (1u << MCP_PIN_JACK));    // inserted = closed to GND
  if (jack != jackLast) {
    jackLast = jack;
    emit("JACK", 0, jack ? 1 : 0);
#if HAS_TPA2016
    if (haveAmp) amp.enableChannel(!jack, !jack);   // headphones in -> speakers off
#endif
  }
  buttonsLast = gpio;
#endif
}

static void pollEncoders() {          // every loop pass (fast)
  static const int8_t table[16] = {0,-1,1,0, 1,0,0,-1, -1,0,0,1, 0,1,-1,0};
  const uint8_t pinsA[2] = {PIN_ENC1_A, PIN_ENC2_A};
  const uint8_t pinsB[2] = {PIN_ENC1_B, PIN_ENC2_B};
  const uint8_t pinsS[2] = {PIN_ENC1_SW, PIN_ENC2_SW};
  const uint8_t btnIds[2] = {BTN_ENC1_PUSH, BTN_ENC2_PUSH};
  for (uint8_t e = 0; e < 2; e++) {
    uint8_t cur = (digitalRead(pinsA[e]) << 1) | digitalRead(pinsB[e]);
    if (cur != encPrev[e]) {
      encAccum[e] += table[(encPrev[e] << 2) | cur];
      encPrev[e] = cur;
    }
    bool sw = digitalRead(pinsS[e]);           // active low
    if (sw != encSwLast[e]) {
      encSwLast[e] = sw;
      emit("BTN", btnIds[e], sw ? 0 : 1);
    }
  }
}

static void taskEncoderReport() {     // ~20 Hz: 4 steps = 1 detent on EC11/PEC11
  for (uint8_t e = 0; e < 2; e++) {
    int8_t detents = encAccum[e] / 4;
    if (detents != 0) {
      encAccum[e] -= detents * 4;
      emit("ENC", e, detents);
    }
  }
}

static void taskBattery() {           // every 5 s
#if HAS_MAX17040
  Wire.beginTransmission(ADDR_MAX17040);
  Wire.write(0x04);                              // SOC register
  if (Wire.endTransmission(false) != 0) return;  // gauge absent — stay quiet
  if (Wire.requestFrom((int)ADDR_MAX17040, 2) != 2) return;
  uint8_t hi = Wire.read(), lo = Wire.read();
  uint16_t socX10 = (uint16_t)hi * 10 + ((uint16_t)lo * 10) / 256;
  if (socX10 > 1000) socX10 = 1000;
  emit("BAT", 0, socX10);
  emit("CHG", 0, digitalRead(PIN_X728_PLD) ? 1 : 0);
#endif
}

static void taskDisplay() {           // ~10 Hz
#if HAS_OLED
  if (!haveOled) return;
  // live position estimate between DISP TIME updates
  uint32_t pos = dispPosMs;
  if (dispDurMs > 0 && dispPosStamp) pos += millis() - dispPosStamp;
  if (dispDurMs > 0 && pos > dispDurMs) pos = dispDurMs;

  char timeStr[12];
  snprintf(timeStr, sizeof(timeStr), "%lu:%02lu",
           (unsigned long)(pos / 60000), (unsigned long)((pos / 1000) % 60));

  oled.clearBuffer();
  oled.setFont(u8g2_font_logisoso28_tn);          // big elapsed time
  oled.drawStr(0, 32, timeStr);

  oled.setFont(u8g2_font_7x13B_tr);               // scrolling title
  int16_t tw = oled.getStrWidth(dispTitle);
  if (tw <= 256) {
    oled.drawStr(0, 60, dispTitle);
  } else {
    marqueeX -= 2;
    if (marqueeX < -(tw + 40)) marqueeX = 0;
    oled.drawStr(marqueeX, 60, dispTitle);
    oled.drawStr(marqueeX + tw + 40, 60, dispTitle);
  }
  if (dispKbps) {                                 // stream info, top right
    char info[24];
    snprintf(info, sizeof(info), "%uk %ukHz", dispKbps, dispKhz);
    oled.setFont(u8g2_font_6x10_tr);
    oled.drawStr(256 - oled.getStrWidth(info), 10, info);
  }
  oled.sendBuffer();
#endif
}

// --------------------------------------------------------------------------- //
// setup / loop
// --------------------------------------------------------------------------- //
void setup() {
  Serial.begin(115200);

  pinMode(PIN_PCA_OE, OUTPUT);
  digitalWrite(PIN_PCA_OE, HIGH);      // motors DISABLED until PCA configured
  pinMode(PIN_X728_PLD, INPUT_PULLUP);
  for (uint8_t i = 0; i < 4; i++) pinMode(PIN_MUX_S[i], OUTPUT);
  analogReadResolution(10);
  const uint8_t encPins[6] = {PIN_ENC1_A, PIN_ENC1_B, PIN_ENC1_SW,
                              PIN_ENC2_A, PIN_ENC2_B, PIN_ENC2_SW};
  for (uint8_t i = 0; i < 6; i++) pinMode(encPins[i], INPUT_PULLUP);

  Wire.begin();                        // GP4/GP5
  Wire.setClock(400000);

#if HAS_PCA9685
  havePcaA = pcaA.begin();
  havePcaB = pcaB.begin();
  for (uint8_t p = 0; p < 2; p++) {
    Adafruit_PWMServoDriver* d = p ? &pcaB : &pcaA;
    if (!(p ? havePcaB : havePcaA)) continue;
    d->setOscillatorFrequency(27000000);
    d->setPWMFreq(1526);               // max — least audible motor buzz
    for (uint8_t c = 0; c < 16; c++) d->setPin(c, 0, false);
  }
  if (havePcaA || havePcaB) digitalWrite(PIN_PCA_OE, LOW);   // outputs now safe
  logmsg(havePcaA ? "pcaA ok" : "pcaA MISSING");
  logmsg(havePcaB ? "pcaB ok" : "pcaB MISSING");
#endif
#if HAS_MPR121
  haveTouch = touch.begin(ADDR_MPR121, &Wire);
  logmsg(haveTouch ? "mpr121 ok" : "mpr121 MISSING");
#endif
#if HAS_MCP23017
  haveMcp = mcp.begin_I2C(ADDR_MCP23017, &Wire);
  if (haveMcp)
    for (uint8_t i = 0; i < 16; i++) mcp.pinMode(i, INPUT_PULLUP);
  logmsg(haveMcp ? "mcp23017 ok" : "mcp23017 MISSING");
#endif
#if HAS_TPA2016
  haveAmp = amp.begin(ADDR_TPA2016, &Wire);
  if (haveAmp) { amp.enableChannel(true, true); amp.setGain(6); }
  logmsg(haveAmp ? "tpa2016 ok" : "tpa2016 MISSING");
#endif
#if HAS_NEOPIXEL
  pixels.begin();
  pixels.clear();
  pixels.show();
#endif
#if HAS_OLED
  haveOled = oled.begin();
  logmsg(haveOled ? "oled ok" : "oled MISSING");
#endif
  logmsg("spotamp-fw ready");
}

void loop() {
  static uint32_t tControl = 0, tTouch = 0, tButtons = 0, tEncRep = 0,
                  tDisplay = 0, tBattery = 0;
  uint32_t now = millis();

  pollSerial();
  pollEncoders();                                 // every pass — quadrature

  if (now - tControl >= (1000 / PID_HZ)) { tControl = now; taskControl(); }
  if (now - tTouch   >= 10)   { tTouch = now;   taskTouch(); }
  if (now - tButtons >= 5)    { tButtons = now; taskButtons(); }
  if (now - tEncRep  >= 50)   { tEncRep = now;  taskEncoderReport(); }
  if (now - tDisplay >= 100)  { tDisplay = now; taskDisplay(); }
  if (now - tBattery >= 5000) { tBattery = now; taskBattery(); }
}

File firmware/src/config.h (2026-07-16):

// SpotAmp — RP2040 firmware configuration.
// Pin assignments mirror hardware/diagrams/pico-pinout.svg — keep them in sync.
#pragma once

#include <Arduino.h>

// ---- feature flags (disable subsystems during bench bring-up) -------------- //
#define HAS_PCA9685   1   // motor PWM (2x, I2C)
#define HAS_MPR121    1   // fader touch-sense
#define HAS_MCP23017  1   // panel buttons + jack detect
#define HAS_TPA2016   1   // speaker amp
#define HAS_MAX17040  1   // X728 fuel gauge (jumpered onto our I2C bus)
#define HAS_OLED      1   // SSD1322 256x64 readout
#define HAS_NEOPIXEL  1

// ---- pins (see pico-pinout.svg) -------------------------------------------- //
// I2C0 (Wire) uses the arduino-pico defaults: SDA=GP4, SCL=GP5.
static const uint8_t PIN_X728_PLD   = 2;    // X728 AC-loss / charge detect
static const uint8_t PIN_PCA_OE     = 3;    // PCA9685 /OE — HIGH = motors disabled
static const uint8_t PIN_MUX_S[4]   = {6, 7, 8, 9};
static const uint8_t PIN_OLED_SCK   = 10;   // software SPI
static const uint8_t PIN_OLED_MOSI  = 11;
static const uint8_t PIN_OLED_DC    = 12;
static const uint8_t PIN_OLED_CS    = 13;
static const uint8_t PIN_OLED_RST   = 14;
static const uint8_t PIN_ENC1_A     = 16;
static const uint8_t PIN_ENC1_B     = 17;
static const uint8_t PIN_ENC1_SW    = 18;
static const uint8_t PIN_ENC2_A     = 19;
static const uint8_t PIN_ENC2_B     = 20;
static const uint8_t PIN_ENC2_SW    = 21;
static const uint8_t PIN_NEOPIXEL   = 22;
static const uint8_t PIN_MUX_ADC    = 26;   // ADC0 <- mux common

// ---- I2C addresses (see hardware/wiring.md address map) -------------------- //
static const uint8_t ADDR_PCA_A     = 0x40; // motors 0-7 (channels 0-15)
static const uint8_t ADDR_PCA_B     = 0x41; // motors 8-9 (channels 0-3)
static const uint8_t ADDR_MCP23017  = 0x20;
static const uint8_t ADDR_MAX17040  = 0x36;
static const uint8_t ADDR_TPA2016   = 0x58;
static const uint8_t ADDR_MPR121    = 0x5A;

// ---- controls --------------------------------------------------------------- //
static const uint8_t NUM_FADERS     = 10;   // 0-6 EQ, 7 preamp, 8 volume, 9 seek
static const uint8_t NUM_BUTTONS    = 13;   // ButtonId 0-12 on MCP pins 0-12
static const uint8_t MCP_PIN_JACK   = 15;   // headphone jack detect (switched TRS)
static const uint8_t BTN_ENC1_PUSH  = 13;   // encoder pushes emit these button ids
static const uint8_t BTN_ENC2_PUSH  = 14;
static const uint8_t MUX_CH_BALANCE = 10;   // wipers 0-9 = faders, 10 = balance pot
static const uint8_t NUM_PIXELS     = 8;

// ---- tuning ----------------------------------------------------------------- //
static const uint16_t FADER_MAX     = 1023; // protocol position range
static const uint16_t PID_HZ        = 250;  // control loop rate
static const float    PID_KP        = 3.0f; // effort per count of error (tune!)
static const float    PID_KD        = 0.8f;
static const uint16_t PID_DEADBAND  = 8;    // counts — close enough, motor off
static const uint16_t REPORT_DELTA  = 5;    // counts — user-move report threshold
static const uint16_t PWM_MAX       = 4095; // PCA9685 full scale
static const uint16_t PWM_MIN_MOVE  = 900;  // stiction floor (tune on bench)

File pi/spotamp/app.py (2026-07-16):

"""Application entry point: main loop, action routing, motor sync.

Responsibilities:
  * poll the playback backend and physical controls
  * route semantic actions (from the UI or the microcontroller) to the backend
  * drive the motorized faders back toward the current state (the magic bit:
    the seek fader physically follows the song, volume follows volume, EQ
    faders snap to the active preset) — unless the user is touching them.
"""

from __future__ import annotations

import sys
import threading
import time

import pygame

from .config import Config
from .controls import (
    ButtonId,
    ControlEvent,
    ControlEventType,
    FaderId,
    FADER_MAX,
    cmd_disp_time,
    cmd_disp_title,
    cmd_fader_target,
    make_controls,
)
from .images import ImageCache
from .library import BrowseState, make_library
from .models import EQ_BANDS, PlaybackStatus
from .power import make_battery
from .spotify import make_backend
from .spotify_web import make_web
from .ui.screen import ScreenUI


class App:
    def __init__(self, cfg: Config) -> None:
        self.cfg = cfg
        pygame.init()
        pygame.display.set_caption("SpotAmp")
        flags = pygame.FULLSCREEN if cfg.fullscreen else 0
        self.surface = pygame.display.set_mode(cfg.window_size, flags)
        if cfg.fullscreen:
            pygame.mouse.set_visible(False)   # touch kiosk — no cursor
        self.clock = pygame.time.Clock()

        # One shared Web API client feeds both playback (webapi backend) and browsing.
        self.web = make_web(cfg)
        self.backend = make_backend(cfg, self.web)
        self.controls = make_controls(cfg)

        # Browsing (real Spotify playlists) + async album art.
        self.images = ImageCache()
        self.screen = ScreenUI(self.surface, self.on_action, self.images)
        self.browse = BrowseState()
        self.library, msg = make_library(self.web)
        if self.library is not None:
            self.browse.loading = True
            self.library.start()
        else:
            print(f"[library] {msg} — using demo playlist")

        self.battery = make_battery(cfg)
        self._battery_accum = 99.0           # read on first frame

        self._grabbed: set[int] = set()      # fader ids the user is touching
        self._last_sent: dict[int, int] = {}  # last target per fader (avoid spam)
        self.running = True

        # Populate the Up Next view for real-playback backends that don't fetch
        # the queue themselves (librespot) — poll the Web API queue off-thread.
        # (Mock playback shows its own playlist; polling the account's real
        # queue there would mismatch what's "playing".)
        if (self.web is not None
                and getattr(self.backend, "real_playback", False)
                and not getattr(self.backend, "populates_queue", False)):
            threading.Thread(target=self._queue_loop, daemon=True).start()

    def _queue_loop(self) -> None:
        while self.running:
            try:
                self.backend.state.queue = self.web.queue()
            except Exception:  # noqa: BLE001
                pass
            time.sleep(4.0)

    # ------------------------------------------------------------------ #
    # action routing (shared by mouse UI and physical controls)
    # ------------------------------------------------------------------ #
    def on_action(self, action: str, **kw) -> None:
        b, st = self.backend, self.backend.state
        if action == "play":
            if st.status is not PlaybackStatus.PLAYING:
                b.play_pause()
        elif action == "play_pause":
            b.play_pause()
        elif action == "stop":
            b.stop()
        elif action == "next":
            b.next()
        elif action == "prev":
            b.prev()
        elif action == "set_view":
            self.screen.set_view(kw["name"])
        elif action == "show_library":       # legacy alias -> Playlists view
            self.screen.set_view("playlists")
        elif action == "open_playlist":
            self._open_playlist(kw["index"])
            self.screen.set_view("now_playing")
        elif action == "seek":
            b.seek(kw["position_ms"])
        elif action == "set_volume":
            b.set_volume(kw["volume"])
        elif action == "set_eq_band":
            b.set_eq_band(kw["band"], kw["gain_db"])
        elif action == "set_preamp":
            st.eq_preamp = max(-12.0, min(12.0, kw["gain_db"]))
        elif action == "select_track":
            b.select_track(kw["index"])
        elif action == "toggle_shuffle":
            b.toggle_shuffle()
        elif action == "cycle_repeat":
            b.cycle_repeat()

    # ------------------------------------------------------------------ #
    # library browsing
    # ------------------------------------------------------------------ #
    def _open_playlist(self, index: int) -> None:
        if not (0 <= index < len(self.browse.playlists)):
            return
        pl = self.browse.playlists[index]
        if getattr(self.backend, "real_playback", False):
            # Play the playlist directly on the device — works for owned AND
            # followed playlists (no tracklist read needed; the Up Next view
            # shows the live queue). This is the on-device path.
            self.backend.play_context(pl.uri)
        elif self.library and pl.owned:
            # Mock/dev: load the tracklist so there's something to simulate.
            self.library.open_playlist(pl)

    def _pump_library(self) -> None:
        if not self.library:
            return
        for kind, payload in self.library.poll():
            if kind == "playlists":
                self.browse.playlists = payload
                self.browse.loading = False
                # prefetch playlist thumbnails so the list looks alive fast
                for pl in payload:
                    if pl.image_url:
                        self.images.get(pl.image_url, (40, 40))
            elif kind == "tracks":
                playlist, tracks = payload
                if tracks:  # mock path only; empty playlists just stay put
                    self.backend.load_tracks(tracks, context_uri=playlist.uri)
            elif kind == "error":
                self.browse.error = str(payload)
                self.browse.loading = False
                print(f"[library] {payload}")
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

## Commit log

2026-07-15 Initial commit: Pi player app, firmware skeleton, hardware docs
    WinAmp-style handheld Spotify player. Runnable desktop mock (Python/Pygame),
    real Spotify Web API browsing + playback (webapi backend), RP2040 firmware
    skeleton with motorized-fader PID, and hardware docs (BOM, wiring, power/battery
    design). Credentials are gitignored; templates provided for public reuse.
2026-07-15 feat(pi): shuffle & repeat via Web API + transport toggles (#8)
    Adds set_shuffle/set_repeat to the Web API client, implements them in
    WebApiPlayer (queued, optimistic), reads shuffle_state/repeat_state in poll,
    and adds shuffle/repeat toggle buttons to the transport row (highlight when on).
    MockPlayer already supported them, so they work in mock mode too.
2026-07-15 feat(pi): battery meter widget + power monitor scaffold (#28, #27)
    Adds power.py (BatterySource abstraction: MockBattery for UI dev, X728Battery
    I2C reader for the Geekworm UPS — untested on hardware), a battery meter in the
    title bar, config options (battery/mock/x728), and an opt-in low-battery safe
    shutdown that only ever fires on real x728 hardware. Closes #28; scaffolds #27
    (real I2C read pending the board).
2026-07-15 docs: Uno Q alternative-platform note + finalize UPS pick (#38, #26)
    Documents the Arduino Uno Q as a v2 single-board candidate (and why we stay on
    Pi 4 B + RP2040 for v1), and commits to the Geekworm X728 UPS for v1 to match
    power.py's X728Battery reader. Closes #38, #26.
2026-07-16 docs: capture Pi bring-up + UI/hardware pivot
    - docs/pi-bringup.md: reproducible standalone-player setup (go-librespot install,
    headless OAuth, audio device fix, systemd service, deploying + running the UI on
    the Wayland session, portrait rotation).
    - deploy/go-librespot.service: the systemd unit.
    - config/go-librespot.example.yaml: explicit audio_device (jack now, USB DAC later).
    - BOM: HyperPixel 4.0 Square display + USB DAC + HyperPixel GPIO/I2S/I2C note
    (battery -> RP2040, audio -> USB, UPS -> USB-C).
    - README + architecture: reflect standalone milestone + physical-first multi-view
    UI direction.
2026-07-16 chore: project tightening — prune dead UI code, view buttons in protocol, pytest suite, doc refresh
    - Prune leftovers from the removed full-skin UI: BrowseState shrunk to
    playlists/loading/error; app.py drops dead view/note/current_playlist writes
    and _device_hint; skin.py loses the old portrait Layout class and mock-legend
    tints; show_hardware_legend config removed. Queue polling now only runs for
    real-playback backends (mock no longer polls the account's queue).
    - Serial protocol: dedicated view-switch buttons (ButtonId 9-11) mapped to
    set_view in the app — preps the physical view buttons (#43).
    - Tests: new pi/tests suite (37 tests) covering the serial protocol, config
    loa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
    [app.py, config.py, library.py]
2026-07-16 feat(hw): hardware-alignment pass — OLED readout, I2C expanders, preset/balance
    From the render audit: the concept's controls are now all scoped and the I/O
    math closes.
    - Amber OLED readout strip (SSD1322 on the RP2040) for time/title/spectrum:
    new DISP TITLE/TIME/INFO serial commands, app streams them (throttled),
    BOM + wiring + firmware docs updated (#51).
    - I/O audit: direct wiring needs ~55 signals vs the Pico's 26 GPIO. Adopted
    2x PCA9685 (motor PWM) + MPR121 (touch) + MCP23017 (buttons) on one I2C bus;
    pin budget documented at 19/26, PWM-buzz caveat noted (#52).
    - ButtonId.EQ_PRESET=12 (preset cycling — the motorized-fader showpiece) and
    PotId.BALANCE=0 (the concept's L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
    [app.py, main.cpp]
2026-07-16 docs(hw): desk wiring-verification pass — I2C map, mux map, safe-boot, battery telemetry
    - I2C address map for all six bus devices (0x20/0x36/0x40/0x41/0x58/0x5A — no
    conflicts) + combined pull-up warning.
    - PCA9685 /OE tied to GP3 with pull-up so uninitialized H-bridges can't jerk the
    motors at boot; per-channel phase stagger note for simultaneous slews.
    - Mux channel map (wipers 0-9, balance 10, 11-15 spare).
    - Battery telemetry: the X728 can't stack on the Pi (HyperPixel owns the header),
    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
2026-07-16 docs(hw): knobs + amp upgrade slot decisions
2026-07-16 feat(cad): parametric front-panel cut drawing (DXF + SVG)
    hardware/cad/: generate_panel.py emits front-panel.dxf (layered, mm, SketchUp-
    ready) and front-panel.svg (Blender-native) from one parametric geometry where
    every dimension is a named, datasheet-traced constant. Layers: OUTLINE/CUTOUTS/
    HOLES/GRILLE/ENGRAVE + REF (behind-panel component bodies) + DIM. Built-in
    checks: interior bounds + all-pairs clearance between every cut feature (>=1.5mm)
    — the checker caught two real collisions during layout (LED slit vs transport,
    grille vs QUEUE button), both fixed; the generator refuses to emit on failure.
    Fourth dimension finding: the fader body is ~106.5mm long (M3 span 80mm), so a
    vertica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
    [front-panel.dxf]
2026-07-16 docs(hw): pop-out kickstand — desktop-device requirement
    The device sits on a desk leaning on a Yanko-style fold-out stand (not pocket
    portable). enclosure.md: flat machined/printed leg on 2x adjustable-torque
    hinges (0-40 deg -> ~70-80 deg face angle), flush stowage pocket + magnetic
    catch, tip-resistance physics (leg >=120mm, feet, battery low as counterweight),
    and the don't-block list (USB-C, switch, thermal pad, antenna window). Hinge
    hardware added to PARTS.
2026-07-16 feat(cad): Concept C — centered screen, 10-band EQ, stereo grilles (220mm)
    The in-between per owner feedback ('B is cool but the vibe is gone'): keeps A's
    symmetric stacked-module composition (the WinAmp/Yanko vibe), gains B's 10-band
    +preamp bank and big speakers — as symmetric L/R grille fields flanking the
    centered screen. Button columns nudged clear of the HyperPixel board edge (3D).
    Geometry checks pass. For the 1:1 paper test.
    [concept-c.dxf]
2026-07-17 feat(cad): Concept D — owner's sketch engineered (220x280, left screen, 10-band)
    Direct translation of the owner's hand sketch: view-key stack top-right,
    6-button transport, function row (LOOP/EQ/PRESET + encoders + balance), screen
    left, grille + 2x2 pot cluster right, seek preserved right-side (sketch omitted
    it), full-width 10-band+preamp EQ. Geometry checks pass; 3D-checked against the
    HyperPixel board footprint.
    [concept-d.dxf]
2026-07-17 chore(cad): panel layout decided — A is final; retire concepts
    Owner decision after 1:1 paper tests: A (175x280, preamp+7-band, centered
    screen) beats concepts B-E — with a 73mm screen window the panel stays
    7-bands-wide so the screen stays the centerpiece. Concepts removed (git
    history preserves them); enclosure doc updated to FINAL.
    [concept-b.dxf, concept-c.dxf, concept-d.dxf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]
2026-07-17 feat(cad): one-motor Yanko-faithful panel design (127x246)
    Consolidated, conflict-free redo of PR #63 on current main. The design: slim
    non-motorized pots for the full classic PRE+10-band EQ + volume + balance at
    the beloved 127mm width; SEEK keeps the single motorized RS60N. Yanko-faithful
    detail pass: WinAmp main-window stack order, 4 sculpted apertures over the one
    256x64 OLED (time+spectrum / title strip / kbps+kHz pills), NOW-PL-QUE round
    toggles, rectangular transport keycaps, bolt badge, ON/AUTO/PRESET EQ header,
    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
    [front-panel-final.dxf]
2026-07-17 feat(cad): brand engrave replaces bolt; aperture + seek-travel notes
    - WinAmp bolt badge removed; engraved "SpotAmp" mark in the brand position
    (drawing + render + script).
    - enclosure.md: OLED 4-aperture implementation notes (active-area constraint,
    +/-0.5mm mask alignment, smoked acrylic layer, firmware region map) and the
    seek-travel decision note (60mm @ 127 wide vs 100mm RSA0N @ ~157 wide).
    [front-panel-final.dxf]
2026-07-17 feat(hw): custom belt-drive seek mechanism — full-width slot at 127mm
    Owner's insight: packaged motorized faders waste ~46mm beyond travel on the
    in-line motor. Replace with a slim manual long-travel pot (~85mm) + remote N20
    motor + GT2 belt loop behind the panel (a mini printer axis) — the seek slot
    now spans ~70% of the face at the beloved width. Electronics/firmware
    unchanged (same wiper feedback, DRV8833, PID). Critical bench item documented:
    backdrivability via slip-clutch pulley. PARTS: ALPS motorized faders removed
    entirely; mechanism parts added (~-\$5 net and every mechanical part printable
    -> machinable). Drawing + render + enclosure notes updated.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
    [front-panel-final.dxf]
2026-07-17 docs(hw): seek mechanism — why output-side sensing beats a servo indicator
    Records the servo-progress-bar consideration and rejection: pot-on-the-knob
    means belt slip is cosmetic and self-correcting; touch-gating means motor
    motion can never issue seeks; servos aren't back-drivable (grab-to-scrub dies).
    Adds the de-risk path: panel is identical motor-or-not, so v1 can ship seek as
    manual-only if the clutch prototype disappoints.
2026-07-17 chore(parts): drop motorized-era rows — no PCA9685s, one DRV8833
    Belt-drive seek + slim pots make the cart: Adafruit ~$98, mechanism kit ~$20,
    slim pots ~$30 — new-parts total ≈ $245-270 (was $450-515 all-motorized).
    Order-of-orders now starts with the clutch prototype (issue #65).
